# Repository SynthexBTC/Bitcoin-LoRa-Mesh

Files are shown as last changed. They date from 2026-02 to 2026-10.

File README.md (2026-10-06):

# Bitcoin-LoRa-Mesh
A decentralized Bitcoin Mesh network that communicates over long-range LoRa radio, enabling off-grid transactions
<br>
Bitcoin Becomes Truly Uncensorable<br>
Broadcast Bitcoin transactions over LoRa mesh networks<br>
No Internet required at the sender's location<br>
<br>
## The nRF52840 E22P868M30S Solar LoRa Node
<br>

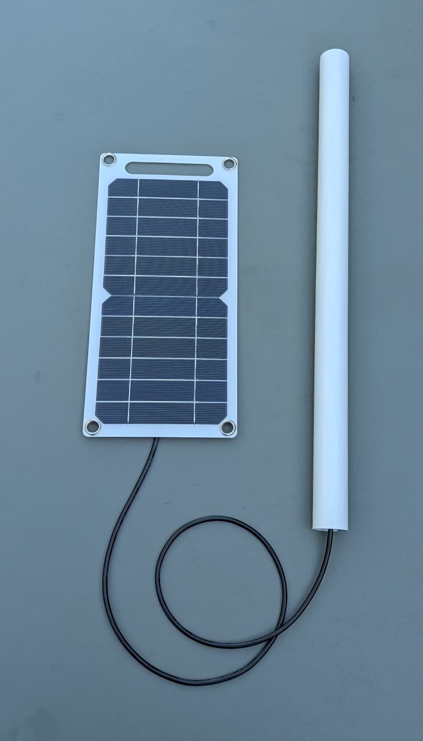
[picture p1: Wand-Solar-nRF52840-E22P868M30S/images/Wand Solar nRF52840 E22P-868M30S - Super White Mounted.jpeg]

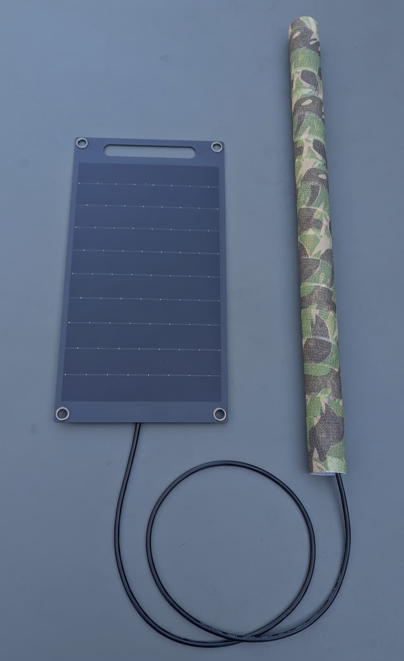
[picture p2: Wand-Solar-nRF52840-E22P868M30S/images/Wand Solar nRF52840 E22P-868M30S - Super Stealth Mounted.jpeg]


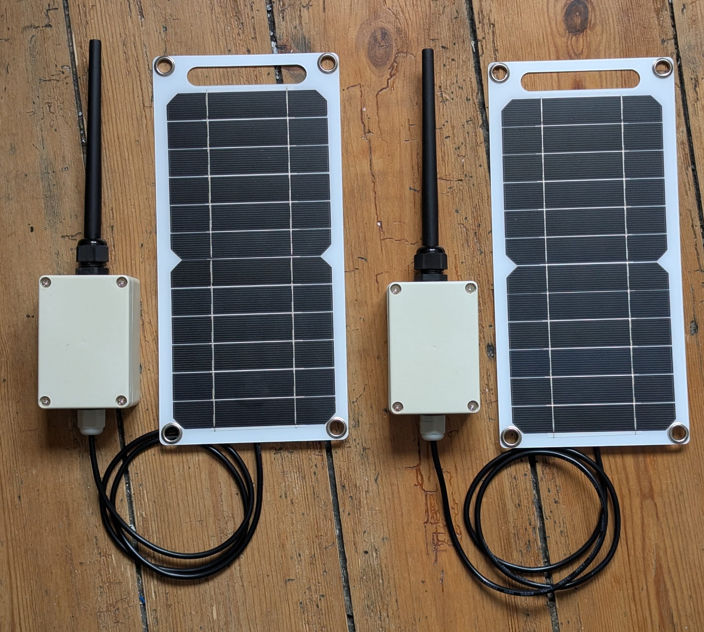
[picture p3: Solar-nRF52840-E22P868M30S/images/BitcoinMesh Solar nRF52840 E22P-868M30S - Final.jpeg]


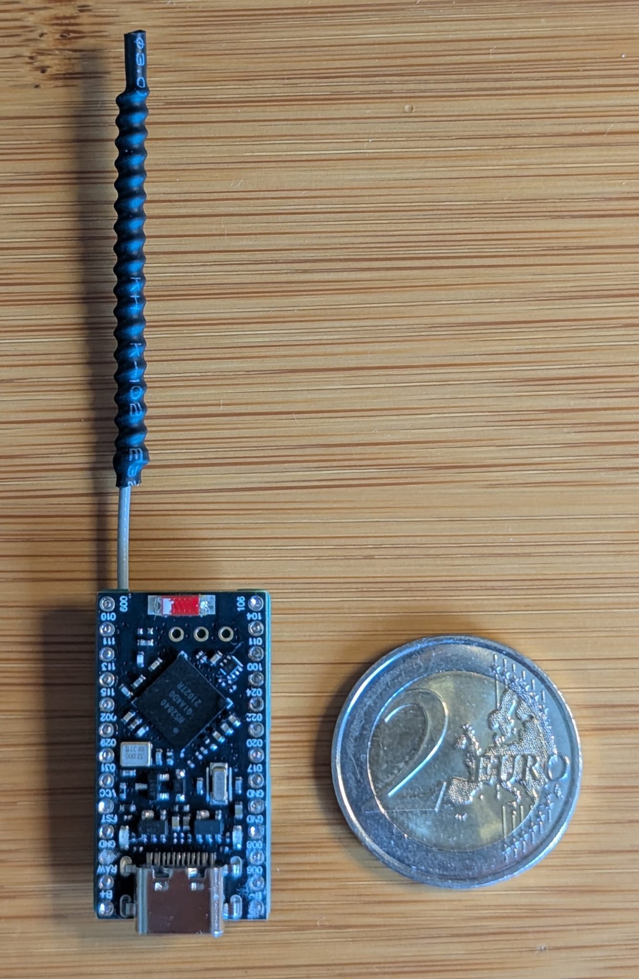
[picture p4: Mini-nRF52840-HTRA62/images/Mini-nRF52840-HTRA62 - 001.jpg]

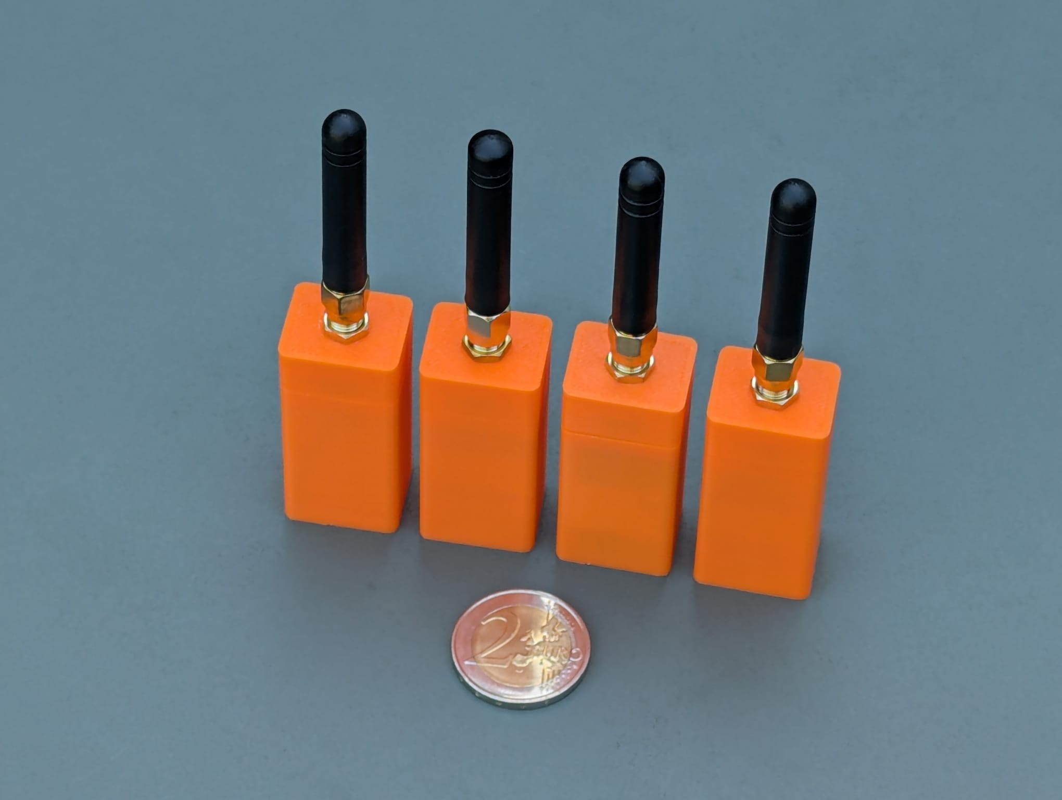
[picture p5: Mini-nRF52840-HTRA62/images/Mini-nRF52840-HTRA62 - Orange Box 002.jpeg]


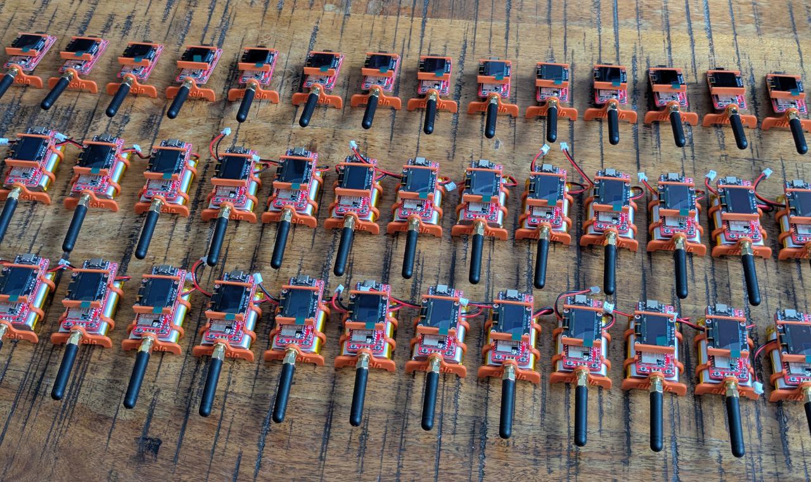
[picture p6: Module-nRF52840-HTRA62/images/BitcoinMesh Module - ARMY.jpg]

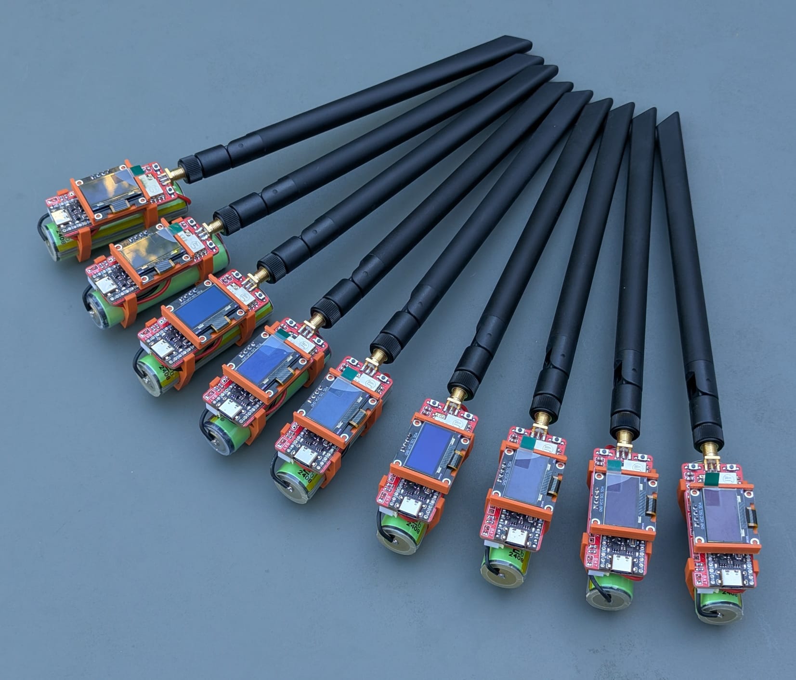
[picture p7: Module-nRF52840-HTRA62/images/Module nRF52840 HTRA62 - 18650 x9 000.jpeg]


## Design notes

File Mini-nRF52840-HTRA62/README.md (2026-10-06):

# Mini nRF52840 SX1262 LoRa Node


  
Ultra Mini and Ultra Low Power LoRa Node  
Only 33mm x 18mm x 8mm !

The total power consumption is 6mA when receiving and about 100mA when transmitting.   
which for Meshcore in "Moderate Repeater" is an average current of **7mA** !
  
Tiny but with Big capabilities :  
- Ultra Low Power nRF52840 SoC
- Bluetooth 5 & Zigbee
- HTRA62 LoRa module with 22dBm power
- TP4054 Li-ion charger for mini solar panel
- Battery voltage monitoring

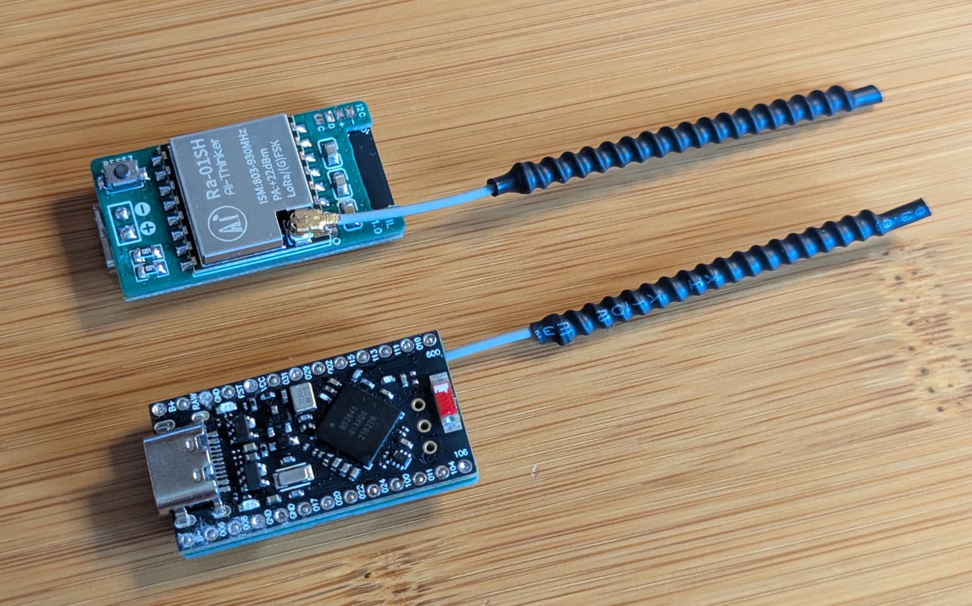
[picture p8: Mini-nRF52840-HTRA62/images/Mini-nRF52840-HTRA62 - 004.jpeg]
  
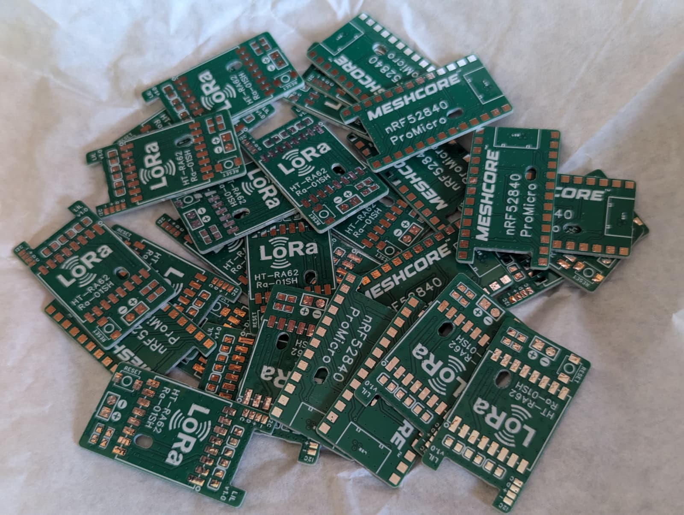
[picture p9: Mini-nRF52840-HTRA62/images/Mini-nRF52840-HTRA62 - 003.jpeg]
  
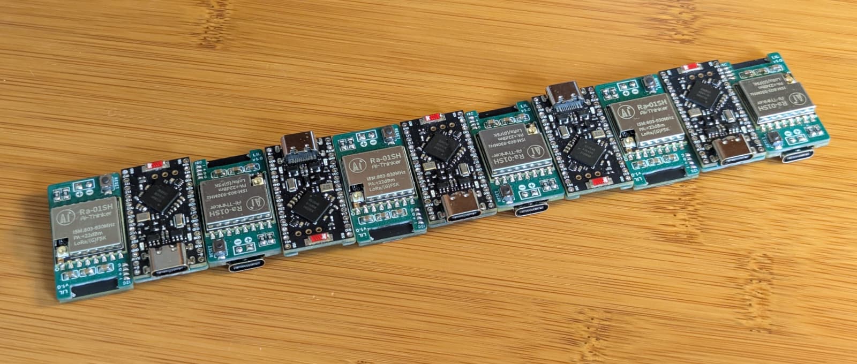
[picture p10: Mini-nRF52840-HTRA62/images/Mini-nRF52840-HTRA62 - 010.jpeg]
  
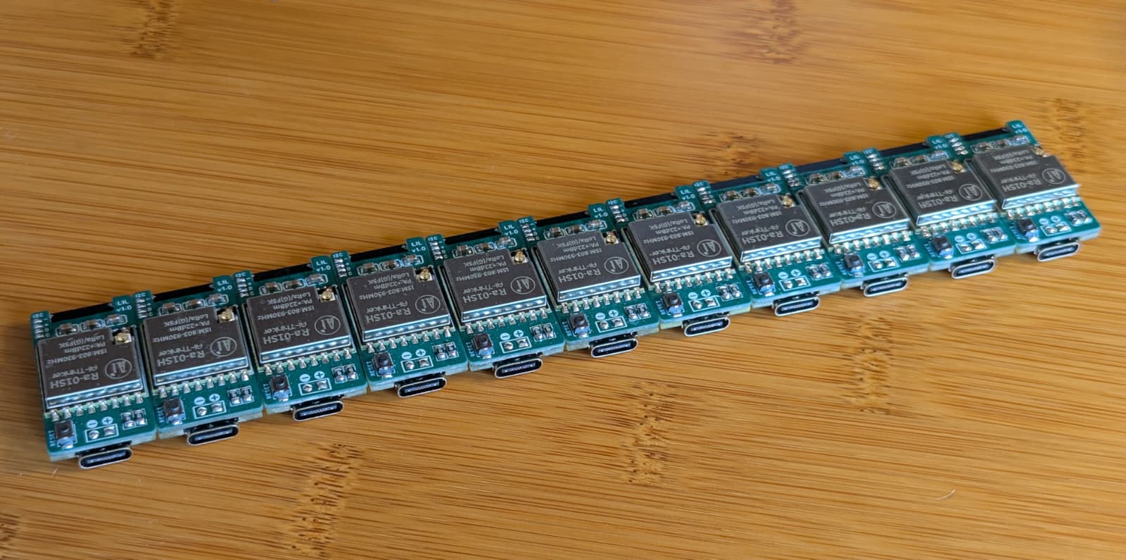
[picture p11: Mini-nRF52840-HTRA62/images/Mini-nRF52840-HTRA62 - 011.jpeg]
  
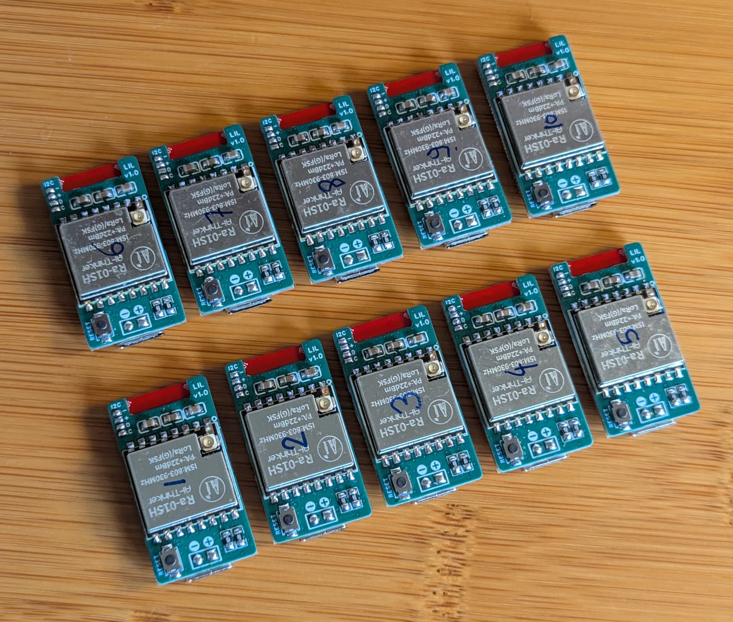
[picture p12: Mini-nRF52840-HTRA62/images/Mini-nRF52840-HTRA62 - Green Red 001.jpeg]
  
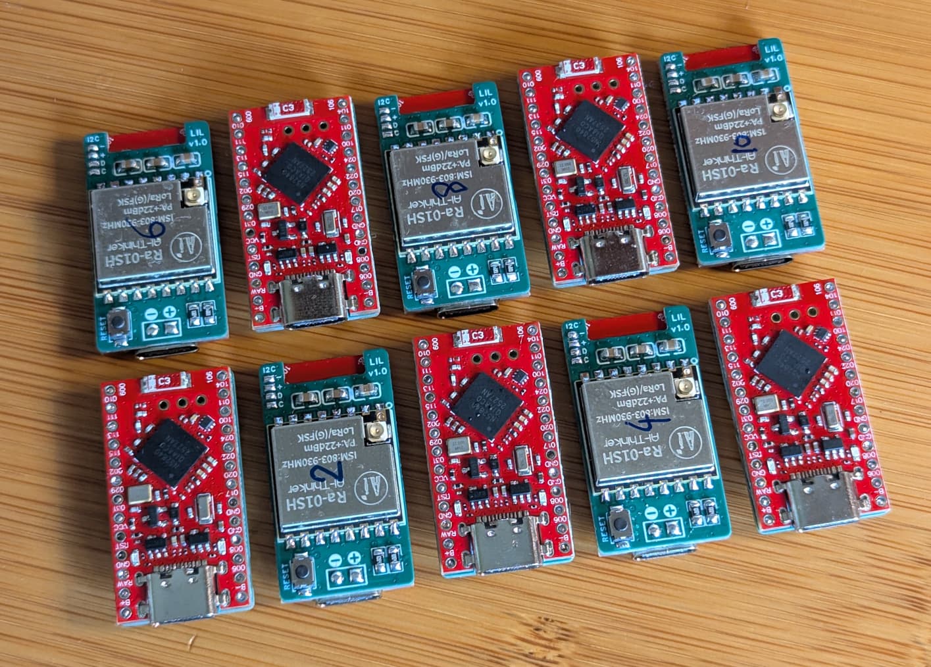
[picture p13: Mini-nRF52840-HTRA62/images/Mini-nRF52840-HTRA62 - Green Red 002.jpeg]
  

### With case and 500mAh 902030 li-Po battery
  
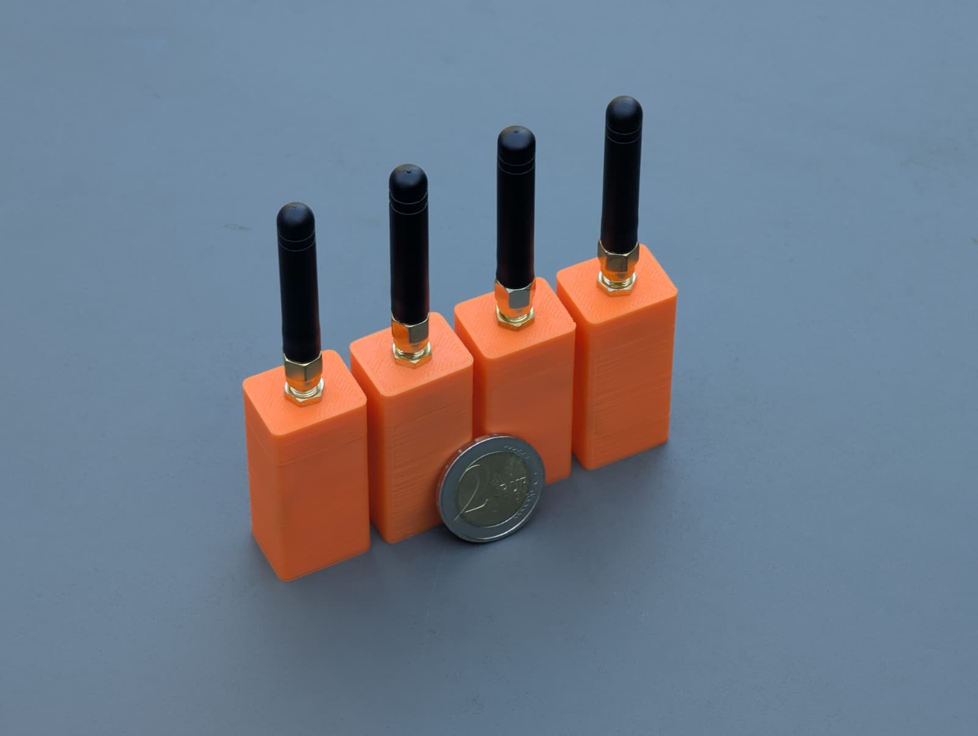
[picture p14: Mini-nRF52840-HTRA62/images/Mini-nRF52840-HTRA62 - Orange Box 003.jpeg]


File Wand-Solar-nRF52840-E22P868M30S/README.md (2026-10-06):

# nRF52840 E22P868M30S Solar Wand LoRa Node

### Super White Wand
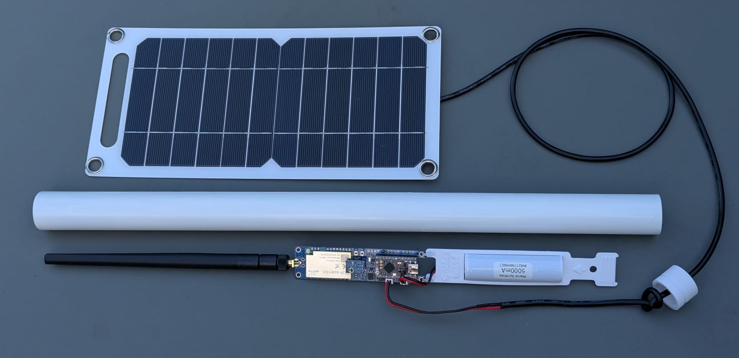
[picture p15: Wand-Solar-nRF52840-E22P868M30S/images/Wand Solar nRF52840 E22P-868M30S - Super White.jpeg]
<p>&nbsp;&nbsp;&nbsp;&nbsp;</p>

### Super Stealth Wand
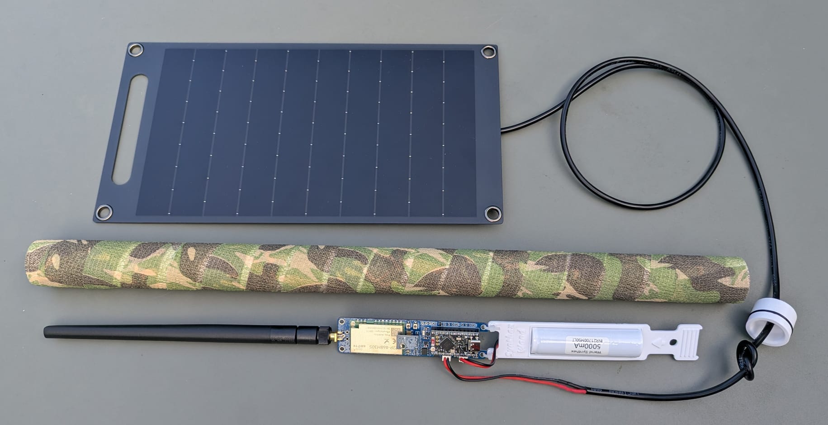
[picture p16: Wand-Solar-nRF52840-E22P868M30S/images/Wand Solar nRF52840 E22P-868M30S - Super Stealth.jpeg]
<p>&nbsp;&nbsp;&nbsp;&nbsp;</p>

<br>
Ultra Low Power Solar LoRa Node (on average 19mA)<br>
Can operate for weeks during the dark days of winter<br>
Compatible with Meshcore, Meshtastic, ...<br>
<br>
•	LoRa module <b>E22P-868M30S</b> (<b>1 Watt</b>, PA up to 32dBm, Ultra LNA, SAW filters, …)<br>
•	<b>nRF52840</b> SoC UltraLow Power<br>
•	Telemetry : Batteries Voltage, Temperature and Humidity (<b>AHT10</b>)<br>
•	<b>Ultra Smart BMS watchdog for the battery via PIC16F13114 : Battery management module that monitors voltage and temperature to automatically protect/cut off/re-enable the battery and charging, 
reset nRF, configurable via USB Serial link : <a href="https://github.com/SynthexBTC/Bitcoin-LoRa-Mesh/tree/main/Wand-Solar-nRF52840-E22P868M30S/watchdog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">INFOS</a><br>
•	18650 or 21700 Li-ion Branded battery with a minimum capacity of 5000 mAh<br>
•	IPX6 resistant enclosure in a <b>32mm diameter</b>, 50cm high rod, containing the antenna, module and batteries<br>
•	<b>Solar Panel</b> waterproof and unbreakable <b>6 Watts Actual</b> (325 cm² = <b>50 square inches</b>)<br>
•	<b>3 dBi antenna</b> (TX868-JKD-20) Tuned with enclosure : SWR≈1 @869,5MHz (with NanoVNA) <br>
<br>
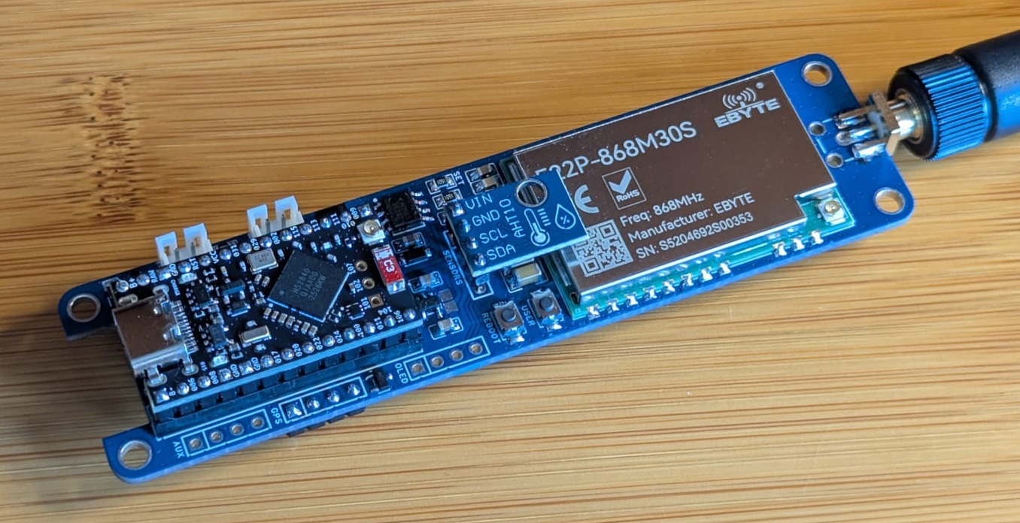
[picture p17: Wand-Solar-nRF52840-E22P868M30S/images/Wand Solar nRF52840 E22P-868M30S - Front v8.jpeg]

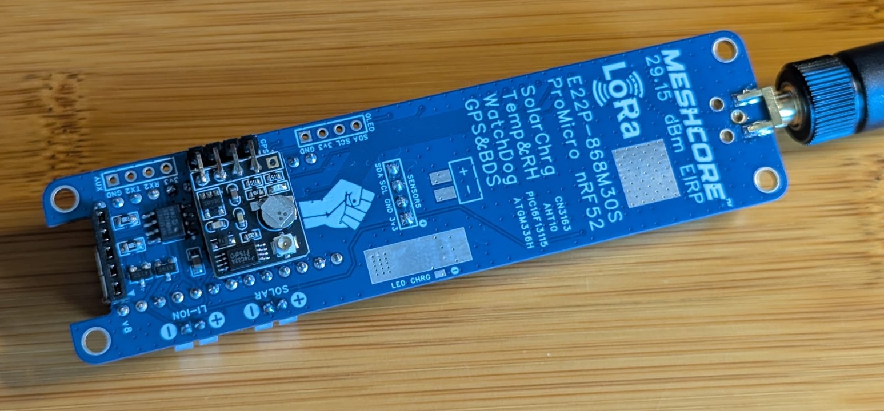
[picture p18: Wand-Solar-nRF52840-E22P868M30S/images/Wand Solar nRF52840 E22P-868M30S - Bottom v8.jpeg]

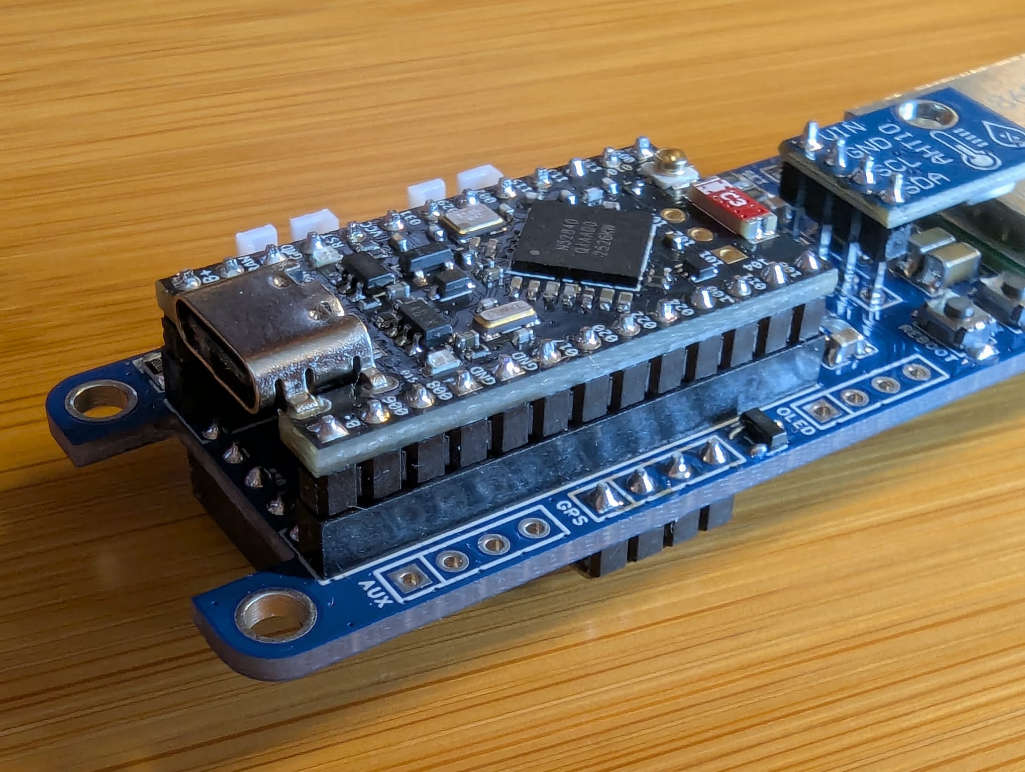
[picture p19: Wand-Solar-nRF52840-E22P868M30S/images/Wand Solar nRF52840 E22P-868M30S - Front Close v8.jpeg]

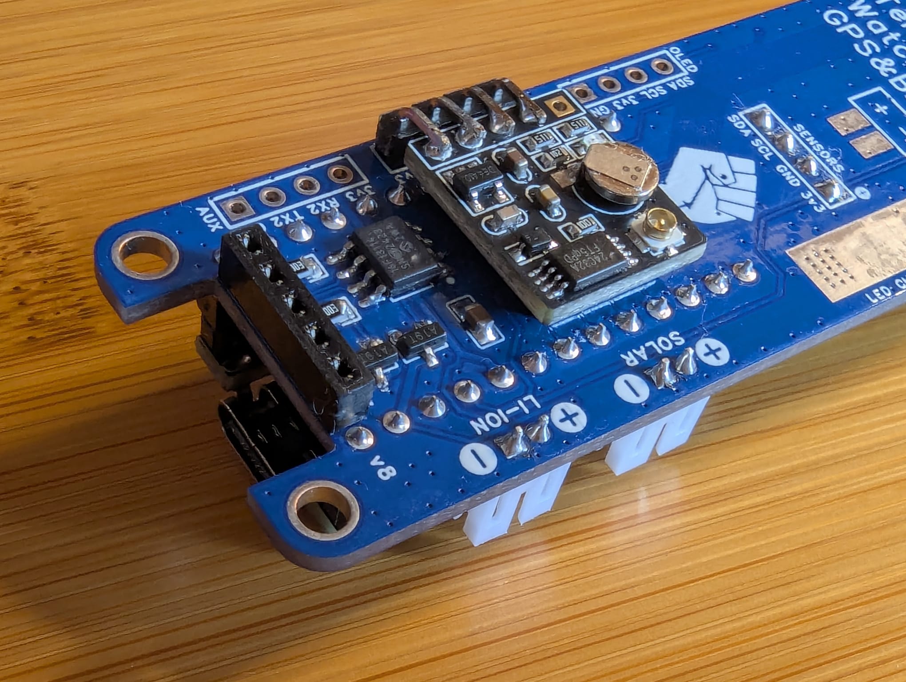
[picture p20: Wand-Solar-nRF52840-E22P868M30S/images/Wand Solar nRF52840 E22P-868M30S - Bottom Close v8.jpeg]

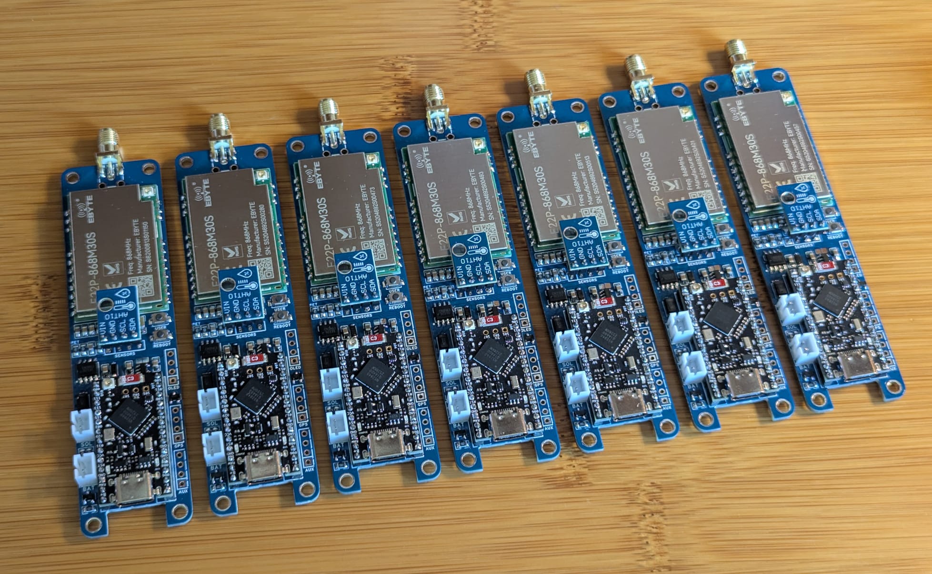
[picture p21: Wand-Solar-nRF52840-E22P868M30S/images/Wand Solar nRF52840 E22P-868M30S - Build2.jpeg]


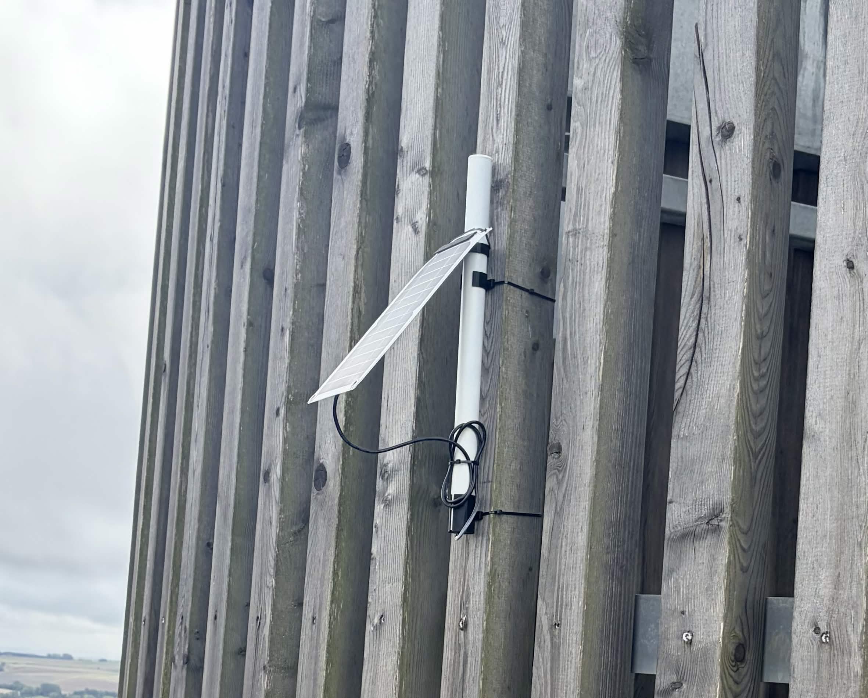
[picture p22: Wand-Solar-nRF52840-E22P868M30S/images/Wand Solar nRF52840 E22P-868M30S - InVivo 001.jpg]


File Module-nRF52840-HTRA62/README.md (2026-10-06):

# BitcoinMesh LoRa Module

BitcoinMesh LoRa Module with UltraLow-Power nRF52840 SoC and 2000mAh LiPo Battery

- Connection via USB or Bluetooth
- OLED Screen
- UltraLow-Power nRF52840 SoC
- HT-RA62 (SX1262) 22dBm LoRa Wireless Module
- On Board LiPo Battery management
- Ready for MESHTASTIC and MESHCORE firmwares

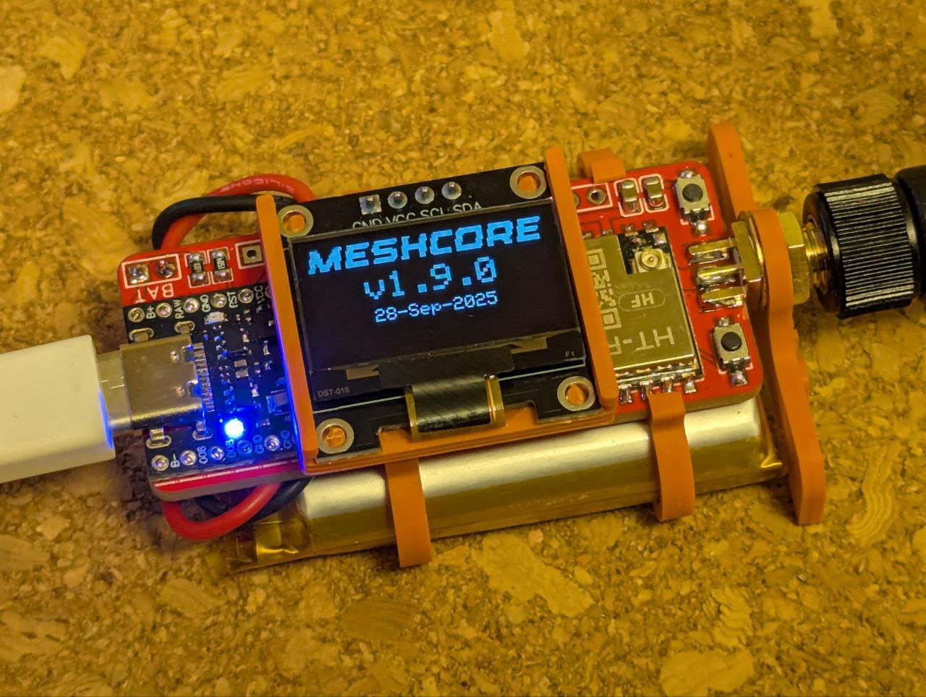
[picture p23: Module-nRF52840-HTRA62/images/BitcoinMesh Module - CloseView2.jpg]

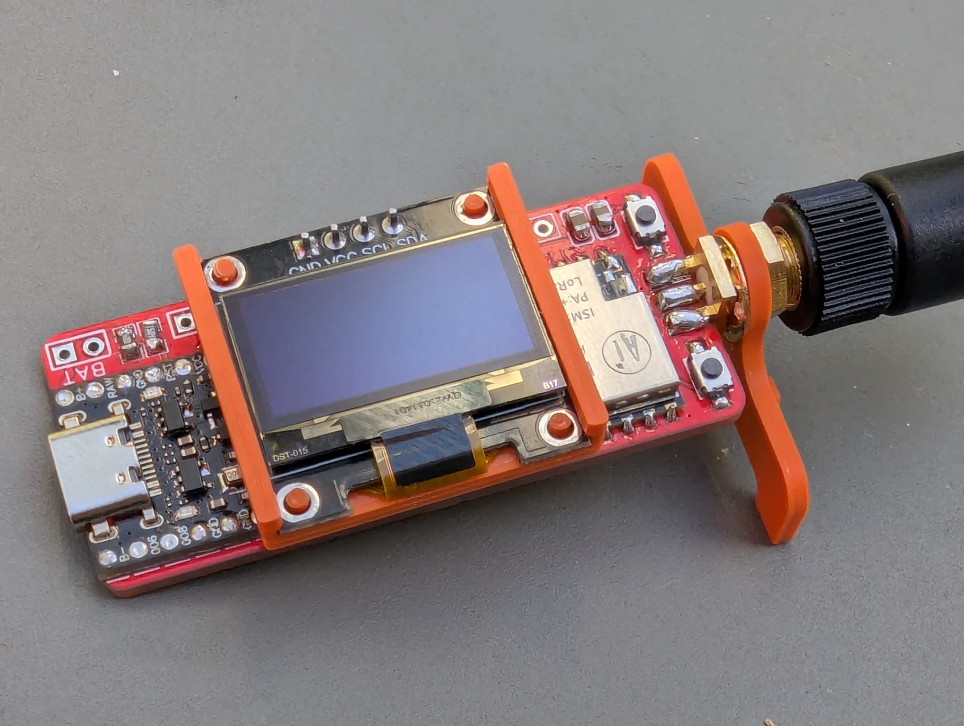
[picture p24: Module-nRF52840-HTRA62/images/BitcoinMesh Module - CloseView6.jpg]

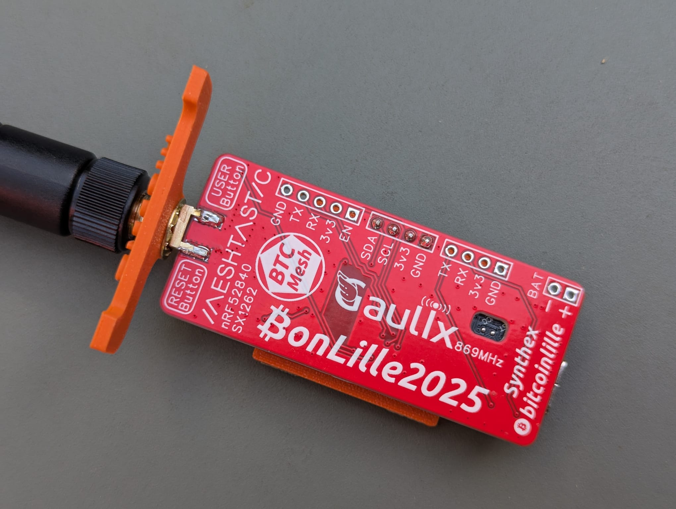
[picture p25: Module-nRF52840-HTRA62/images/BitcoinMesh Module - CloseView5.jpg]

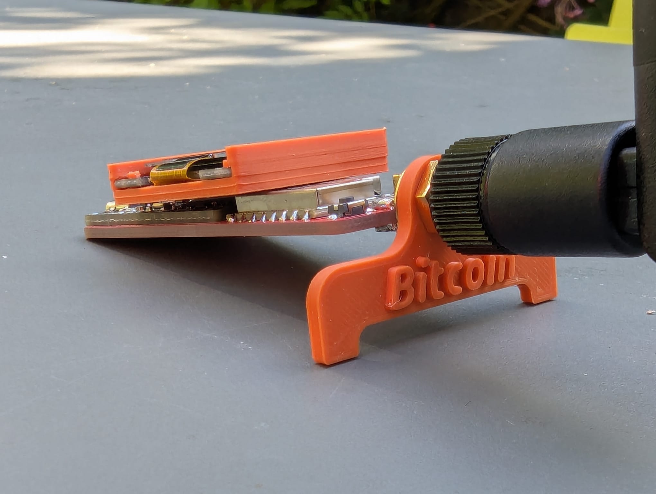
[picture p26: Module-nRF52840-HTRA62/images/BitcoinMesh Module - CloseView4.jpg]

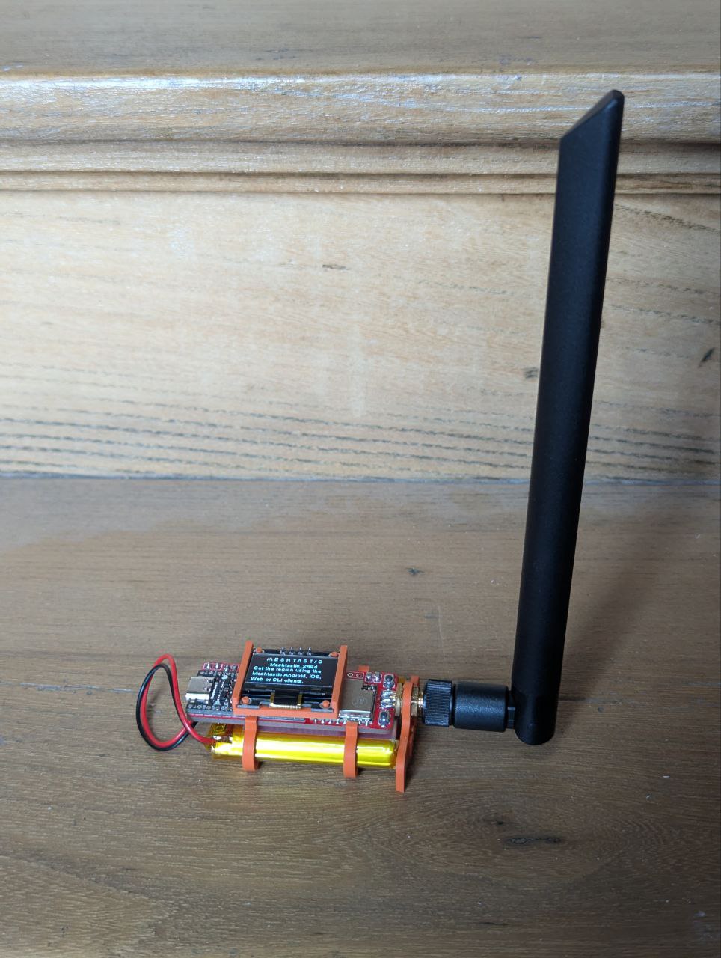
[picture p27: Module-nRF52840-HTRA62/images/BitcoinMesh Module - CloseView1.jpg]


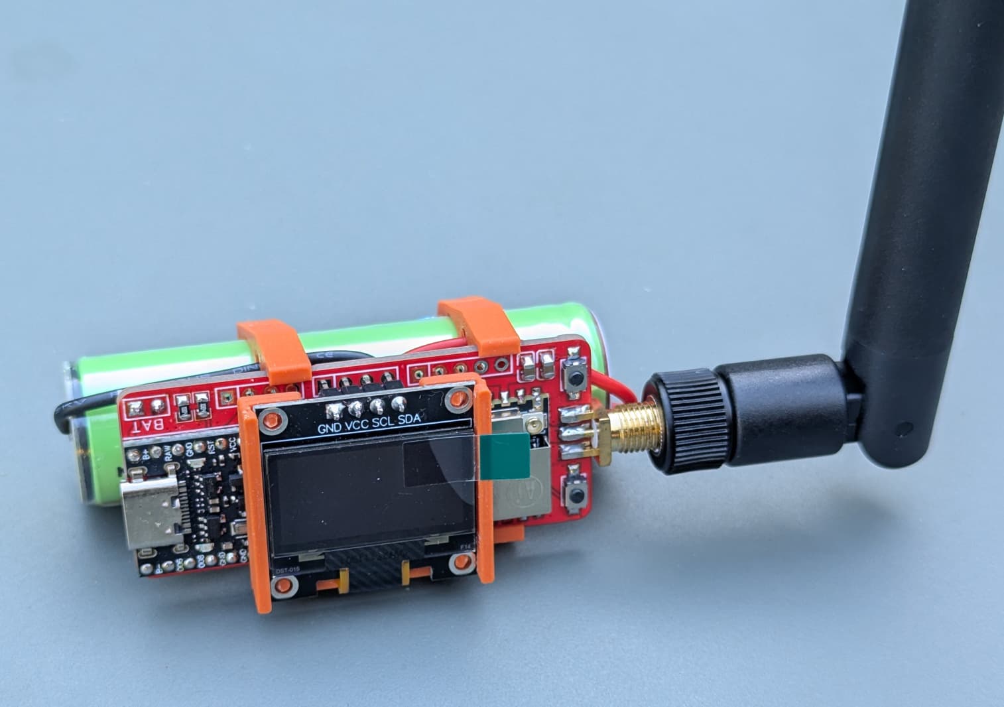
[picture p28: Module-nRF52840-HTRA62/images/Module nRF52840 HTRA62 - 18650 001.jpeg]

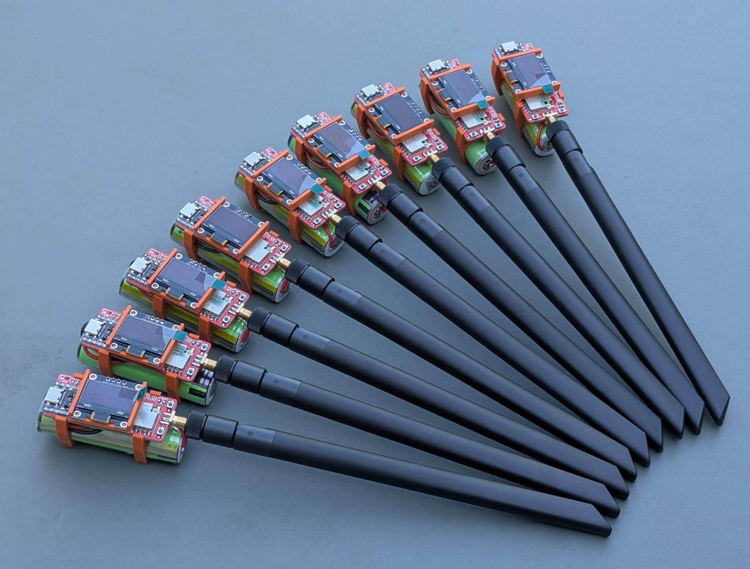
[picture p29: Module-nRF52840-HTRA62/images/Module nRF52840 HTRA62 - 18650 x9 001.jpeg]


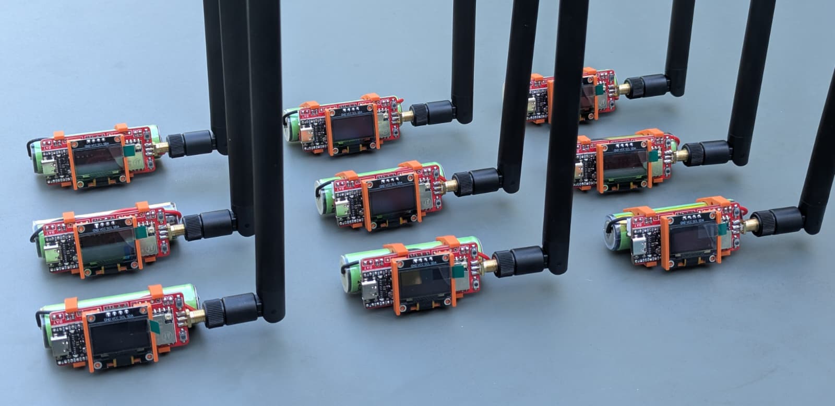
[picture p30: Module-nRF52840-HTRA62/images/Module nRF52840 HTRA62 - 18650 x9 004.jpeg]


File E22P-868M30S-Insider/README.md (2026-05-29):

# Why use E22P-868M30S

A completely new generation, coming out at the end of 2025 !<br>

This module adds a true RF front end module (RF FEM) comprising :
- A power amplifier (PA) up to 32 dBm at 868 MHz (see datasheet)
- A low-noise amplifier (LNA)
- Several surface acoustic wave (SAW) filters
- RF Ceramic Chips
- A high-precision active temperature compensated crystal oscillator

Compared to the previous old generation E22-900M30S,<br>
these modules significantly improve out-of-band spurious signal suppression capabilities,<br>
and offer enhanced anti-interference capabilities as well as increased receive sensitivity.<br>

<br>

Change of pin name from E22-900M30S to E22P-868M30S :
- RXEN pin is now EN pin
- TXEN pin is now T/R CTRL pin

The EN pin must now always be set to ON.<br>
However, to ensure good confuguration, full power and reduced floor noise,<br><b>it must be grounded for 3 seconds during startup !</b><br>
<br>

## Power Output @868MHz (dBm) - SX1262 Power Setting (dBm) - Power Supply (V) 
<table>
  <thead>
    <tr>
      <th>Pset</th>
      <th>5.0 V</th>
      <th>4.2 V</th>
      <th>3.7 V</th>
      <th>3.3 V</th>
    </tr>
  </thead>
  <tbody>
    <tr><th>-9</th><td>11.7</td><td>11.2</td><td>10.9</td><td>10.7</td></tr>
    <tr><th>-8</th><td>12.7</td><td>12.2</td><td>11.9</td><td>11.7</td></tr>
    <tr><th>-7</th><td>13.7</td><td>13.2</td><td>12.9</td><td>12.7</td></tr>
    <tr><th>-6</th><td>14.7</td><td>14.2</td><td>13.9</td><td>13.7</td></tr>
    <tr><th>-5</th><td>15.7</td><td>15.2</td><td>14.9</td><td>14.7</td></tr>
    <tr><th>-4</th><td>16.7</td><td>16.2</td><td>15.9</td><td>15.7</td></tr>
    <tr><th>-3</th><td>17.7</td><td>17.2</td><td>16.9</td><td>16.7</td></tr>
    <tr><th>-2</th><td>18.7</td><td>18.2</td><td>17.9</td><td>17.7</td></tr>
    <tr><th>-1</th><td>19.7</td><td>19.2</td><td>18.9</td><td>18.7</td></tr>
    <tr><th>0</th><td>20.7</td><td>20.2</td><td>19.9</td><td>19.7</td></tr>
    <tr><th>1</th><td>21.7</td><td>21.2</td><td>20.9</td><td>20.7</td></tr>
    <tr><th>2</th><td>22.7</td><td>22.2</td><td>21.9</td><td>21.7</td></tr>
    <tr><th>3</th><td>23.7</td><td>23.2</td><td>22.9</td><td>22.7</td></tr>
    <tr><th>4</th><td>24.7</td><td>24.2</td><td>23.9</td><td>23.7</td></tr>
    <tr><th>5</th><td>25.7</td><td>25.2</td><td>24.9</td><td>24.7</td></tr>
    <tr><th>6</th><td>26.6</td><td>26.1</td><td>25.8</td><td>25.6</td></tr>
    <tr><th>7</th><td>27.6</td><td>27.1</td><td>26.8</td><td>26.6</td></tr>
    <tr><th>8</th><td>28.5</td><td>27.9</td><td>27.6</td><td>27.4</td></tr>
    <tr><th>9</th><td>29.4</td><td>28.6</td><td>28.3</td><td>28.0</td></tr>
    <tr><th>10</th><td>30.3</td><td>29.3</td><td>28.8</td><td>28.4</td></tr>
    <tr><th>11</th><td>30.7</td><td>29.6</td><td>29.1</td><td>28.6</td></tr>
    <tr><th>12</th><td>31.1</td><td>29.9</td><td>29.4</td><td>28.8</td></tr>
    <tr><th>13</th><td>31.4</td><td>30.2</td><td>29.6</td><td>28.9</td></tr>
    <tr><th>14</th><td>31.6</td><td>30.4</td><td>29.8</td><td>29.0</td></tr>
    <tr><th>15</th><td>31.8</td><td>30.6</td><td>29.9</td><td>29.0</td></tr>
    <tr><th>16</th><td>31.9</td><td>30.7</td><td>29.9</td><td>29.0</td></tr>
    <tr><th>17</th><td>32.0</td><td>30.8</td><td>30.0</td><td>29.0</td></tr>
    <tr><th>18</th><td>32.0</td><td>30.9</td><td>30.0</td><td>29.0</td></tr>
    <tr><th>19</th><td>32.1</td><td>30.9</td><td>30.0</td><td>29.0</td></tr>
    <tr><th>20</th><td>32.1</td><td>31.0</td><td>30.0</td><td>29.0</td></tr>
    <tr><th>21</th><td>32.1</td><td>31.0</td><td>30.0</td><td>29.0</td></tr>
    <tr><th>22</th><td>32.0</td><td>31.0</td><td>30.0</td><td>29.0</td></tr>
  </tbody>
</table>

<br>

## SF8301

The SF8301 is a Surface Acoustic Wave (SAW) filter, commonly used for high-frequency signal conditioning :
- Center Frequency: 868 MHz
- Bandwidth: 10 MHz

SAW Filters provide high-performance frequency selection, effectively separating and filtering signals from different frequency bands.<br>
This ensures smooth communication between communication devices while suppressing interference.<br>
This is essential for use in urban areas with Cellular mobile networks.<br>
<br>
Several surface acoustic wave (SAW) filters in E22P-868M30S is a game changer !

<br>

## KCT8102L

KCT8102L is a highly-integrated, RF Front-End Integrated Circuit which incorporates key RF functionality needed for a TDD-mode operating in the 860M to 930MHz ISM frequency bands. <br>
KCT8102L is integrated with a power amplifier (PA), a low noise amplifier (LNA) with bypass, and a single-pole, double-throw (SPDT) switch all in one device. <br>
KCT8102L is designed for ease of use and maximum flexibility, with different matching circuits, KCT8102L could achieve high power and high efficiency two operation status.<br>
KCT8102L has simple and low-voltage 1.6 to 3.6V control logic, and wide supply voltage range from 3.0 to 5.25V allowing the KCT8102L to be used in battery powered applications.<br>
KCT8102L is assembled in a compact, low-profile 3x3x0.77mm 16-lead LGA package. KCT8102L is the ideal RF front-end solution for implementing sub-GHz from 860M to 930MHz supporting multiple standards including LP-WAN (LoRa, Sigfox, etc.), Wi-SUN, and other loT applications.<br>
<br>
Integrated high-performance 860 to 930MHz Front-End Module<br>
Nominated voltage at 3.3V & 4.2V & 5V<br>
<br>
<b>+32.5dBm saturated output power at 5.0V High Power Matching</b><br>
+31.0dBm saturated output power at 5.0V High Efficiency Matching<br>
+31.0dBm saturated output power at 4.2V High Power Matching<br>
+29.5dBm saturated output power at 4.2V High Efficiency Matching<br>
+29.0dBm saturated output power at 3.3V High Power Matching<br>
+27.5dBm saturated output power at 3.3V High Efficiency Matching<br>
<br>
Integrated LNA with noise figure of 1.7dB at 5V & 4.2V & 3.3V<br>
Receive bypass path with low loss: 2.0dB at 5V & 4.2V & 3.3V<br>
Support external Receive filter<br>
ESD Protection Circuitry on All Ports<br>
Small package: LGA-16L, 3×3×0.77mm (MSL3, 260°C per JEDEC J-STD-020)<br>
RoHS and REACH Compliant<br>

<br>
<br>

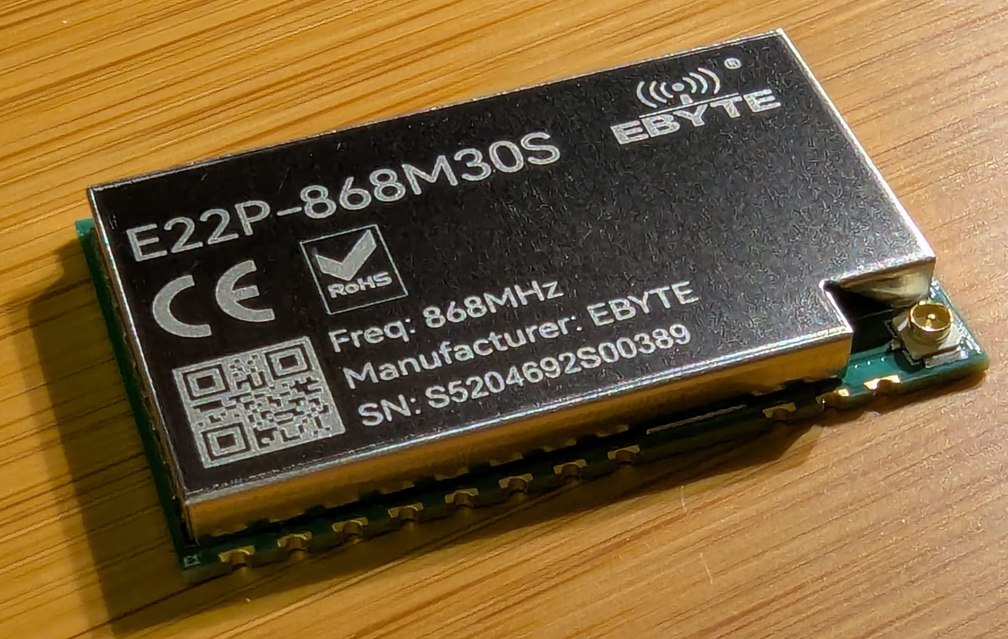
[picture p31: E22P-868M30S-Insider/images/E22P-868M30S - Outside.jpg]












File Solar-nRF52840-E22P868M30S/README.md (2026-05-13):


<br>

<br>

# nRF52840 E22P868M30S Solar LoRa Node
<br>
Ultra Low Power Solar LoRa Node (about 25mA)<br>
Can operate for weeks during the dark days of winter<br>
Compatible with Reticulum, Meshcore, Meshtastic, ...<br>
<br>
•	LoRa module <b>E22P-868M30S</b> (<b>1 Watt</b>, PA up to 32dBm, Ultra LNA, SAW filters, …)<br>
•	<b>nRF52840</b> SoC UltraLow Power<br>
•	Configuration OLED Screen<br>
•	Telemetry : Temperature and Humidity (<b>AHT20</b>)<br>
•	Telemetry : Batteries Voltage and Current (<b>INA219</b>)<br>
•	Watchdog and Scheduled <b>Automatic Reboot ever 1, 7 or 30 days</b> (PIC <b>16F13124</b>)<br>
•	RGB LED : Displays battery charging and Watchdog status<br>
•	Battery charging protection <b>NTC sensor</b>, temperature range from -2°C to 55°C<br>
•	<b>Dual-independent</b> battery protection. If one fails, the other works (2* DW07D)<br>
•	2* 18650 Li-ion batteries (<b>Lii-King4000</b>) for a total actual capacity of 7000mAh<br>
•	IP68 waterproof enclosure + double cable glands<br>
•	<b>Solar Panel</b> waterproof and unbreakable <b>6 Watts Actual</b> (325 cm² = <b>50 square inches</b>)<br>
•	<b>3 dBi antenna</b> (TX868-JKD-20) Tuned with enclosure : SWR≈1 @869,5MHz (with NanoVNA) <br>
•	Dedicated 64Mb Flash memory (W25Q64JV) to <b>Reticulum Transport Node</b> (Path table) <br>
<br>
To be at the maximum permitted power in Europe : <b>29,15 dBm EIRP</b>, <br>
The LoRa output power (sx1262) must be set to <b>8 dBm</b> in Meshtatic, Meshcore, RTNode, …<br>
<br>

<br>

<br>

<br>


<br>

<br>

<br>

<br>

<br>

<br>

<br>

<br>


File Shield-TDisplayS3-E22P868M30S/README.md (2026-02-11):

# T-Display-S3

T-Display-S3 is a board whose main control chip is ESP32-S3 N16R8.<br>
It is equipped with a 1.9-inch LCD color screen and two programmable buttons.

It is very well known in the Bitcoin world, as it is widely used by NerdMiners !

Adding an E22P-868M30S LoRa module makes it look like the Heltec Vision Master T190 (HT-VMT190), but much better !
- Better LoRa module (much, much more power and sensitivity)
- Better LCD quality (The screen bus is 8 bits wide, which allows for greater fluidity)



# T-Display-S3 - E22P-868M30S add-on board with IPX connector





# T-Display-S3 - E22P-868M30S add-on board with SMA connector






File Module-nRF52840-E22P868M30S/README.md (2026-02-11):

# BitcoinMesh LoRa HighPower Module

BitcoinMesh LoRa Module with E22P-868M30S 1Watt power output !

- Connection via Bluetooth
- OLED Screen
- UltraLow-Power nRF52840 SoC
- E22P-868M30S (SX1262) HighPower 1W+ LoRa Wireless Module
- On Board DC-DC regulator
- Ready for MESHTASTIC and MESHCORE firmwares
- Automatic humidity and temperature telemetry
- Can be mounted in a PVC pipe directly on the roof with the antenna

<p align="left">


</p>
<p align="left">

</p>





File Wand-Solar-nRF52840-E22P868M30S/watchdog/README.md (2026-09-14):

# Wand Smart Battery Management System

Battery **voltage** and **temperature** watchdog based on a PIC16F13114 microcontroller.



## What it does

This little module keeps an eye on your power and temperature, and takes care of your battery automatically.  

Every 16 seconds, it wakes up, takes a quick look at the power level and the temperature, then goes back to sleep.

## Operating Logic

- **At startup**: `BAT_EN` is set to the "battery disabled" state, a pulse is sent on `RESET_CPU`, then the module goes into permanent sleep (WDT wake-up every 16 s).
- **On each wake-up**, the module measures VDD and temperature, then applies the following rules:
  - If VDD stays **below the low threshold** `BAT_LOW_MV` for the confirmation duration `BAT_LOW_S` (10 min by default) → the battery is **disabled** (`BAT_EN` cut off).
  - If VDD exceeds the **re-enable threshold** `BAT_OK_MV` (after confirmation `BAT_OK_S`) → the battery is **re-enabled** (`BAT_EN`), followed by a pulse on `RESET_CPU`.
  - If VDD exceeds the **overvoltage threshold** `BAT_HIGH_MV` for the confirmation duration `BAT_HIGH_S` → **charging is disabled** (`CHRG_EN`), independently of the temperature-based charging window below. It is **re-enabled** only once VDD has been back at or below `BAT_HIGH_MV` for `BAT_HIGH_S` as well (symmetric confirmation on both edges of this threshold, no instant hysteresis).
  - If temperature goes outside the range `[TEMP_LOW_C ; TEMP_HIGH_C]` (0 °C to 47 °C by default) → **charging is disabled** (`CHRG_EN`); within the normal range, charging is allowed **unless** the overvoltage cutoff above is also active (`CHRG_EN` follows the logical AND of "temperature in range" and "no overvoltage cutoff").
  - If temperature exceeds `TEMP_DANGER_HIGH_C` (65 °C by default) or drops below `TEMP_DANGER_LOW_C` (-20 °C by default) → **total safety shutdown** (both battery and charging disabled), with absolute priority over any other logic.
  - When temperature returns to the normal range after a thermal emergency, the battery is **re-enabled immediately** (without waiting for the `BAT_OK_MV`/`BAT_OK_S` confirmation), provided VDD is not below the low threshold.

- **Periodic Reboot**, Automatic reboot period after `REBOOT_D` days. (battery cutoff/re-enable + nRF52840 reset pulse)

- **The key feature lies in the management of the reset (RESET_BTN) and, above all, the complete shutdown (BAT_EN) of the Meshcore board. This makes it possible to reboot even the most stubborn boards and fully discharge the capacitors to ensure a clean restart.**


  




⚠️ **Note on timing accuracy**: the module only wakes up every 16 seconds (no real-time clock). Confirmation durations (`BAT_LOW_S`, `BAT_OK_S`, `BAT_HIGH_S`) are therefore always **rounded up to the next multiple of 16 s**. For example, an entered value between 1 and 16 s results in an actual delay of 16 s, between 17 and 32 s an actual delay of 32 s, and so on. The value stored and read back via `GET` remains exactly the one entered; only the physically observed delay is quantized in 16 s steps (always rounded up, so never less protective than requested — at worst 15 s more).

## Power consumption

About half a microamp on average, low enough to run for years on a battery.

---

## Connecting for Configuration (Serial Link)

Configuration is done via the module's ICSP port, connected to a USB-to-serial adapter.

| ICSP Port | ↔ | USB-Serial Adapter |
|---|---|---|
| pin 1  | ↔ |  |
| pin 2  | ↔ |  |
| pin 3 = GND | ↔ | GND |
| pin 4 = ICSPDAT = **TX** | ↔ | **RX** |
| pin 5 = ICSPCLK = **RX** | ↔ | **TX** |

**Serial link parameters:**

- Speed: **1200 baud**
- Format: **8N1** (8 data bits, no parity, 1 stop bit)

**Please note : the Wand must be powered by its own battery to be configured.**





---

## Command Syntax

Two commands are available:

- `GET NAME` → response `NAME=value` or `ERR` (or, for `GET INFOS`, a multi-line response, see below)
- `SET NAME value` → response `OK` or `ERR`

**Important: a successful `SET` immediately saves all parameters to Flash memory** (no separate save command needed).

Commands and parameter names are case-insensitive.

---

## Read-Only Commands (Not Adjustable)

| Command | Description | Response |
|---|---|---|
| `GET TEMP` or `GET TEMPERATURE` | Current temperature | in °C |
| `GET VOLTAGE` or `GET MV` | Current VDD voltage | in mV (0 = measurement failure) |
| `GET VERSION` or `GET VER` | Firmware version | version string |
| `GET INFOS` | Summary of the main thresholds, grouped by topic | 4 lines — see format below |

### `GET INFOS` response format

One line per group, current values separated by ` ; `:

```
BAT_MV : BAT_LOW_MV ; BAT_OK_MV ; BAT_HIGH_MV
BAT_S : BAT_LOW_S ; BAT_OK_S ; BAT_HIGH_S
TEMP_C : TEMP_DANGER_LOW_C ; TEMP_LOW_C ; TEMP_HIGH_C ; TEMP_DANGER_HIGH_C
REBOOT_D : REBOOT_D
```

---

## Adjustable Parameters (GET/SET)

| Name | Meaning | Unit | Min | Max | Default |
|---|---|---|---|---|---|
| `BAT_LOW_MV` | VDD low threshold → disables `BAT_EN` (after confirmation `BAT_LOW_S`) | mV | 0 | 8191 | 3300 |
| `BAT_OK_MV` | VDD re-enable threshold → re-enables `BAT_EN` + `RESET_CPU` pulse (after confirmation `BAT_OK_S`) | mV | 0 | 8191 | 3800 |
| `BAT_LOW_S` | Confirmation duration before battery shutdown, 16 s resolution | s | 0 | 4080 | 600 |
| `BAT_OK_S` | Confirmation duration before re-enabling `BAT_EN`, 16 s resolution | s | 0 | 4080 | 0 |
| `BAT_HIGH_MV` | VDD overvoltage threshold → disables `CHRG_EN` (charging), independently of `TEMP_LOW_C`/`TEMP_HIGH_C` below (after confirmation `BAT_HIGH_S`) | mV | 0 | 8191 | 4280 |
| `BAT_HIGH_S` | Confirmation duration, applied both before disabling and before re-enabling `CHRG_EN` on the `BAT_HIGH_MV` threshold (symmetric), 16 s resolution | s | 0 | 4080 | 0 |
| `TEMP_LOW_C` | Below this threshold → `CHRG_EN` disabled | °C | -8192 | 8191 | 0 |
| `TEMP_HIGH_C` | Above this threshold → `CHRG_EN` disabled | °C | -8192 | 8191 | 47 |
| `TEMP_DANGER_HIGH_C` | Above this threshold → total shutdown (`BAT_EN` + `CHRG_EN`) | °C | -8192 | 8191 | 65 |
| `TEMP_DANGER_LOW_C` | Below this threshold → total shutdown (`BAT_EN` + `CHRG_EN`) | °C | -8192 | 8191 | -20 |
| `TEMP_OFFSET_C` | Additive offset applied to the temperature reading (measured_c + offset) | °C | -8192 | 8191 | -2 |
| `REBOOT_D` | Automatic reboot period (battery cut/re-enable + reset pulse); 0 = disabled | days | 0 | 8191 | 0 |
| `RESET_PULSE_MS` | Duration of the `RESET_CPU` pulse | ms | 0 | 8191 | 1000 |
| `BAT_CUT_PULSE_MS` | Duration of `BAT_EN` cutoff (at startup and before each periodic reboot) | ms | 0 | 8191 | 5000 |

---

## Example Session

```
> GET VERSION
VERSION=v8.2.6

> GET TEMP
TEMP=23

> GET VOLTAGE
VOLTAGE=3980

> SET BAT_LOW_MV 3200
OK

> GET BAT_LOW_MV
BAT_LOW_MV=3200

> SET BAT_LOW_MV 99999
ERR

> GET INFOS
BAT_MV : 3200 ; 3800 ; 4280
BAT_S : 600 ; 0 ; 0
TEMP_C : -20 ; 0 ; 47 ; 65
REBOOT_D : 0
```

(`ERR` is returned if the parameter name is unknown, if the value is not a valid integer, or if it is outside the Min/Max bounds listed above.)

---

## Points of Attention for the User

- A `VOLTAGE`/`MV` value of **0** indicates a **voltage measurement failure**, not an actual zero voltage (physically impossible during normal operation).
- The total safety shutdown (high or low thermal emergency) takes **absolute priority over all VDD/charging logic**: it applies even when voltage conditions would normally call for re-enabling the battery.
- `BAT_OK_MV`/`BAT_OK_S` control **re-enabling the battery** (`BAT_EN`); `BAT_HIGH_MV`/`BAT_HIGH_S` are a **separate, independent** overvoltage cutoff on **charging** (`CHRG_EN`) only, the two thresholds are not related and can be set independently.
- The `TEMP_OFFSET_C` offset defaults to **-2 °C** (drift compensation); any value read via `GET TEMP` already includes this offset.
- Any change made via `SET` is **saved immediately and automatically** to Flash memory, it is therefore retained after a power loss.

---

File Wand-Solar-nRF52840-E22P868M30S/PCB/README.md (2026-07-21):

&nbsp;&nbsp;&nbsp;&nbsp;&nbsp;&nbsp;

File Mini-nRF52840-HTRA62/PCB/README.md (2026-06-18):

&nbsp;&nbsp;&nbsp;&nbsp;&nbsp;&nbsp;

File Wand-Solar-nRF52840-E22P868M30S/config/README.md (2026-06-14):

# MeshCore Repeater Admin Configuration

## Initial Setup Commands

Run these commands via the CLI after flashing the firmware.

---

### Clock Synchronization
Sync the node clock from the connected GNSS module.
```
gps sync
```

---

### Power Management
Enable powersaving mode to reduce current consumption between LoRa events.
```
powersaving on
```

---

### Radio Configuration
Set frequency, bandwidth, spreading factor and coding rate.
```
set radio 869.618,62.5,8,8
```

| Parameter | Value | Description |
|---|---|---|
| Frequency | `869.618` MHz | EU868 band |
| Bandwidth | `62.5` kHz | |
| Spreading Factor | `8` | SF8 |
| Coding Rate | `8` | CR 4/8 |

---

### TX Power
Set transmit power in dBm.  
  
The power output must be set to 22 dBm.  
With the E22P-868M30S module powered by 3.3 volts, the output is approximately 28 dBm.  
The antenna gain is approximately 1.7 dBi and considering losses in connectors, we are therefore close to the legal limit of 29.15 dBm.  
```
set tx 22
```
> Maximum allowed value for the SX1262 in EU868: **22 dBm**.

---

### Duty Cycle
Set the airtime duty cycle limit.
```
set dutycycle 10
```
> 10% duty cycle — compliant with EU868 regulatory requirements.

---

## Full Setup Sequence

```
gps sync
set radio 869.618,62.5,8,8
set tx 22
set dutycycle 10
powersaving on
```

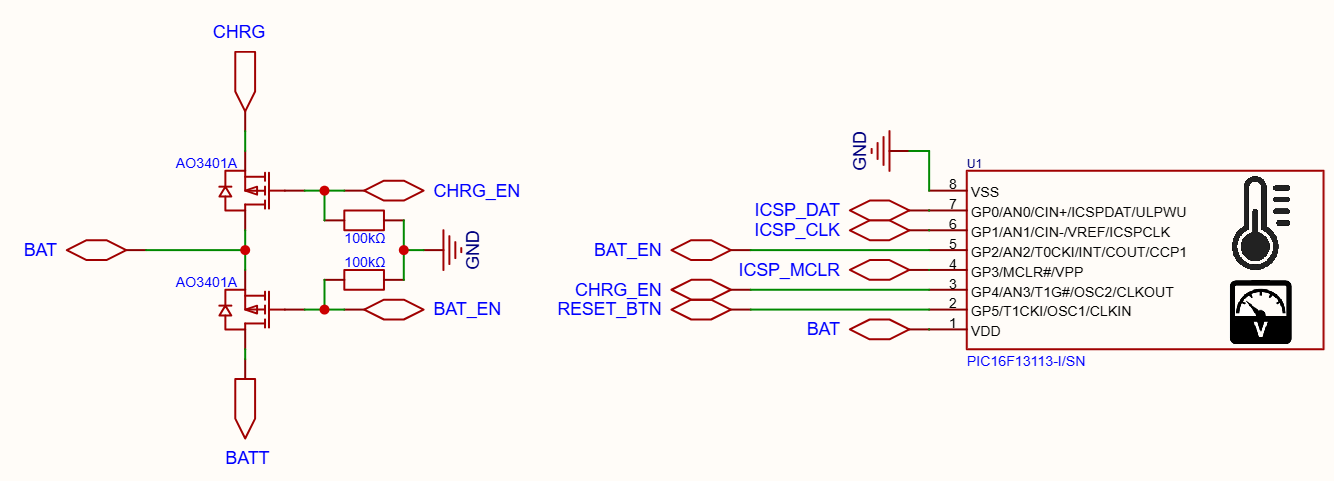
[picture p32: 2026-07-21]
Wand-Solar-nRF52840-E22P868M30S/images/Wand Solar nRF52840 E22P-868M30S - Schematics v8 WatchDog.png

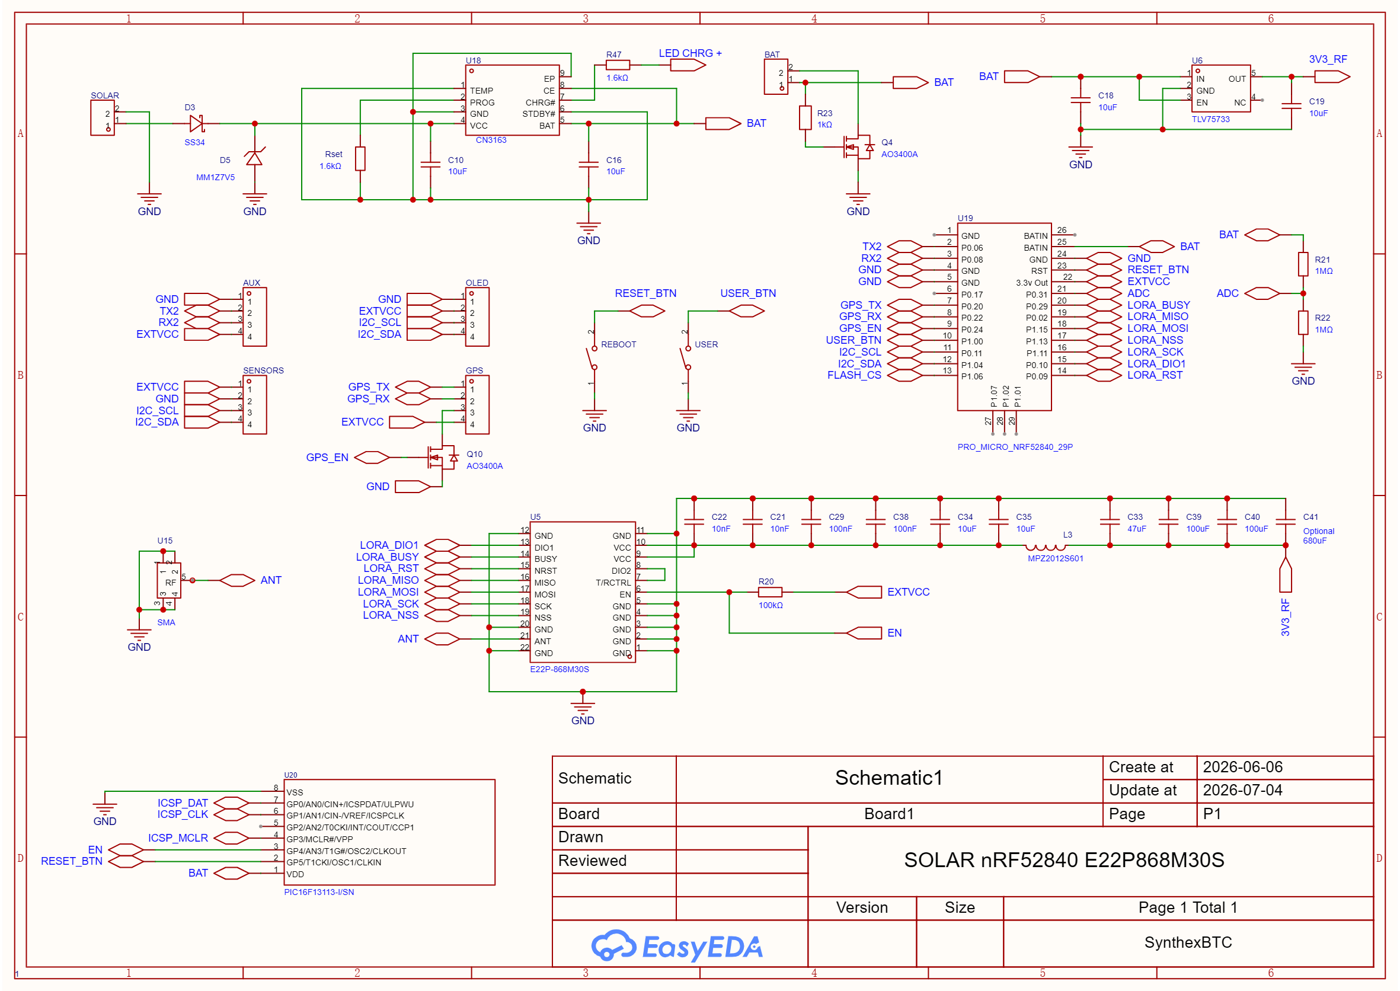
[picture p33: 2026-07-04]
Wand-Solar-nRF52840-E22P868M30S/images/Wand Solar nRF52840 E22P-868M30S - Schematics v6.png

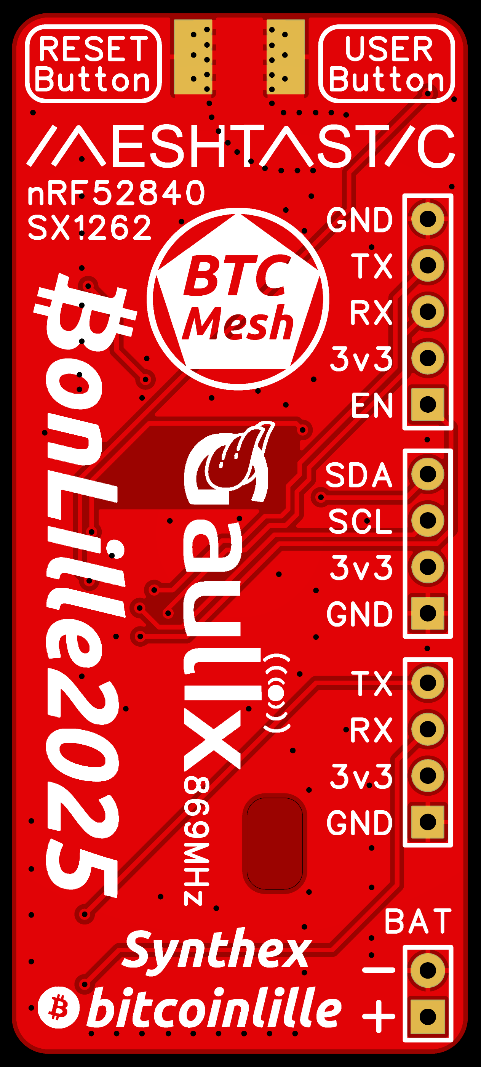
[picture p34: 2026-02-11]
Module-nRF52840-HTRA62/images/BitcoinMesh Module nRF52840 - PCB Bottom.png

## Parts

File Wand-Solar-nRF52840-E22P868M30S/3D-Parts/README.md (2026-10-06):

## 3D Parts

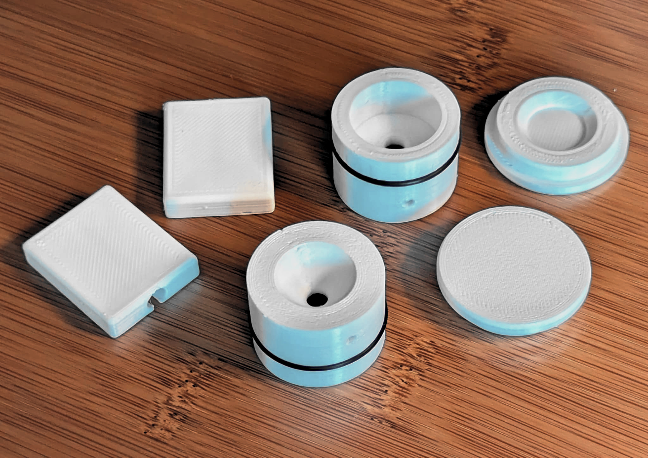
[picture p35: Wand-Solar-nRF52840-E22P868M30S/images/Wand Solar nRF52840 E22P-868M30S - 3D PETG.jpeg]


## 32mm PVC pipe

**BE CAREFUL** when choosing the 32mm PVC pipe !  
The internal diameter **must be at least 28mm**.  
Some low-quality pipes have a much smaller diameter.  

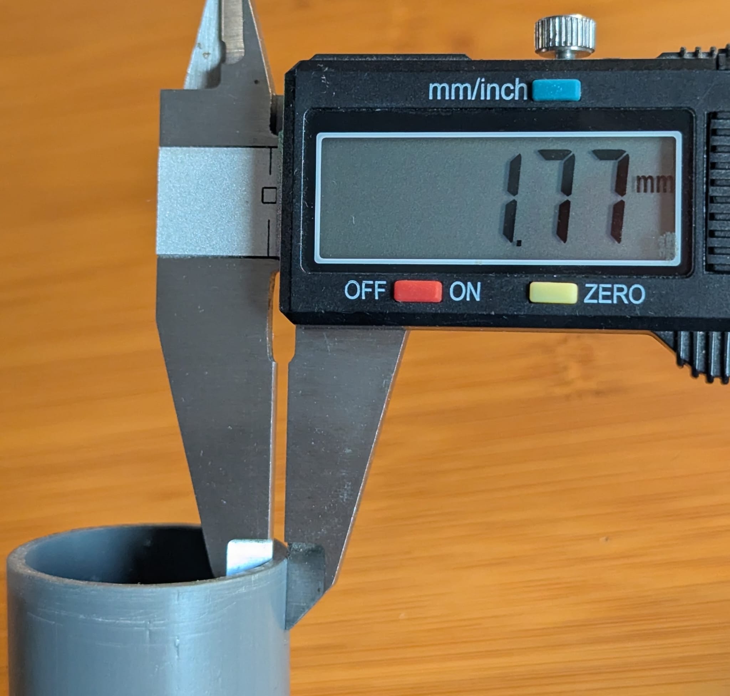
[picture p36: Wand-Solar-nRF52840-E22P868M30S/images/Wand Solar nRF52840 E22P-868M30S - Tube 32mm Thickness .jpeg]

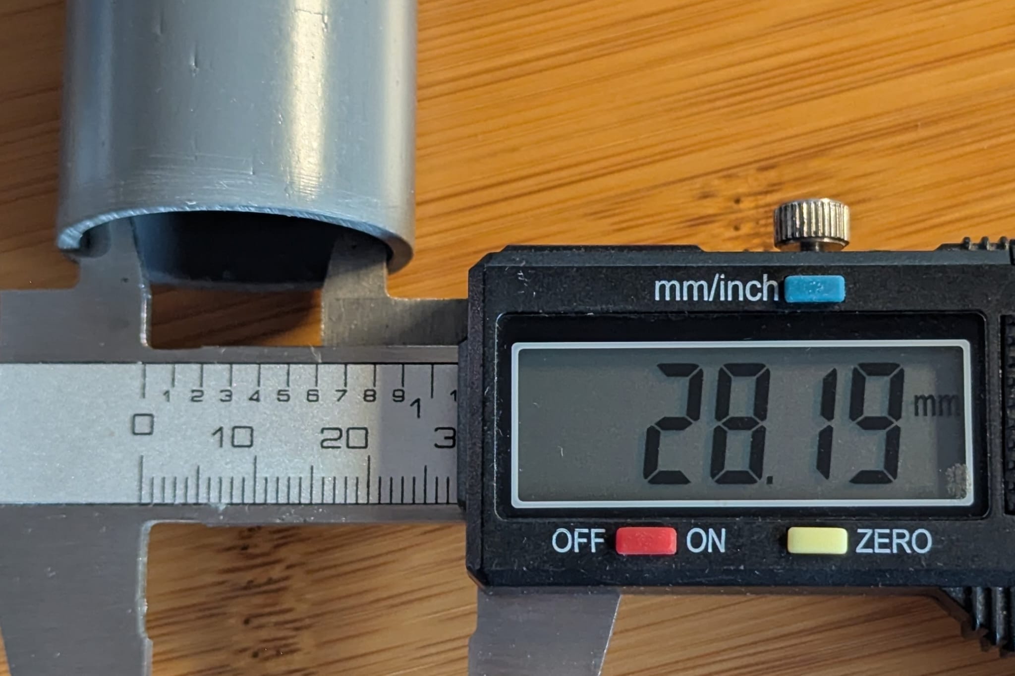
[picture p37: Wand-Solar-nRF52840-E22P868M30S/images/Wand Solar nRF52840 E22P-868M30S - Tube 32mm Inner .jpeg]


<table border="1">
  <tr><th>Top</th><th>Bottom</th></tr>
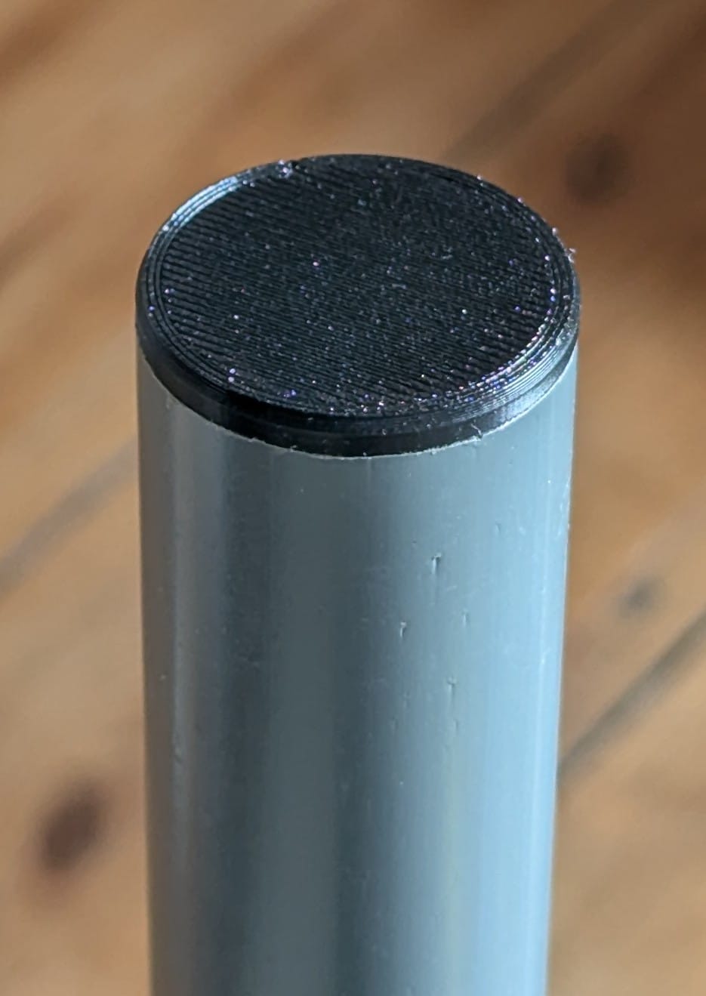
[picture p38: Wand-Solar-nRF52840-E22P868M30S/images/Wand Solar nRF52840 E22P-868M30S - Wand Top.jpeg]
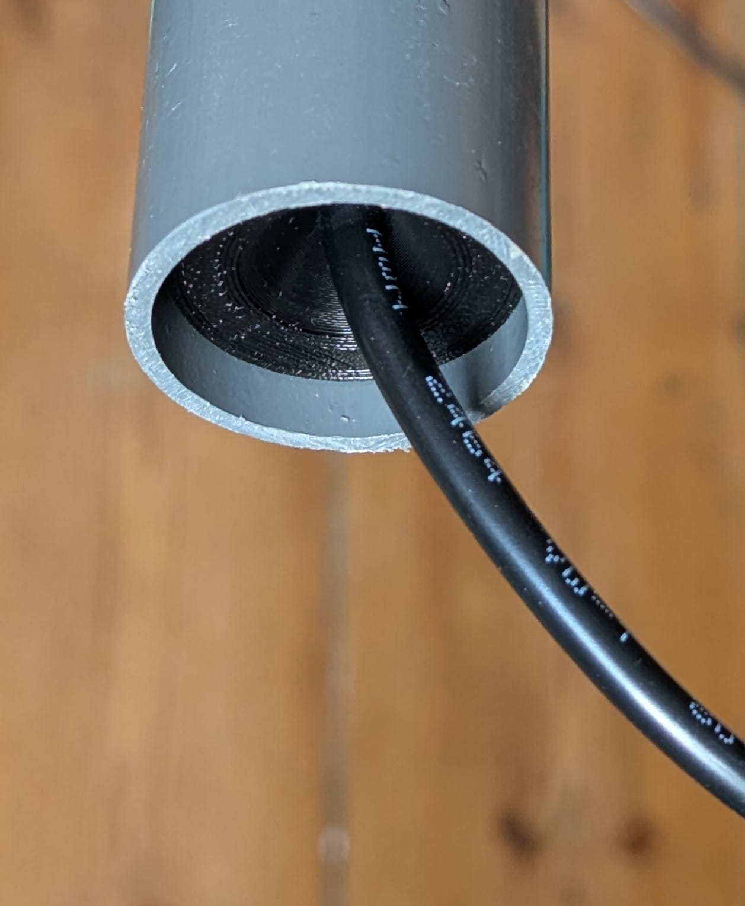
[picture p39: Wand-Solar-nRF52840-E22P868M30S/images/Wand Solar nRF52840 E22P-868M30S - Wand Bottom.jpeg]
  <tr><td></td><td></td></tr>
  <tr><td>The top is glued directly onto the tube.</td><td>The bottom contains an O-ring and is held in place by a screw on the side.</td></tr>
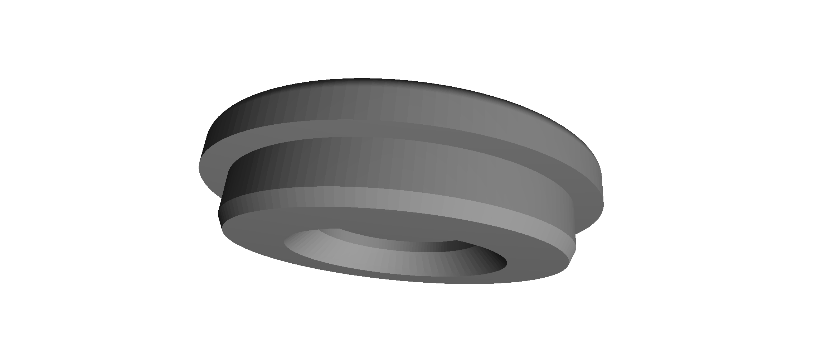
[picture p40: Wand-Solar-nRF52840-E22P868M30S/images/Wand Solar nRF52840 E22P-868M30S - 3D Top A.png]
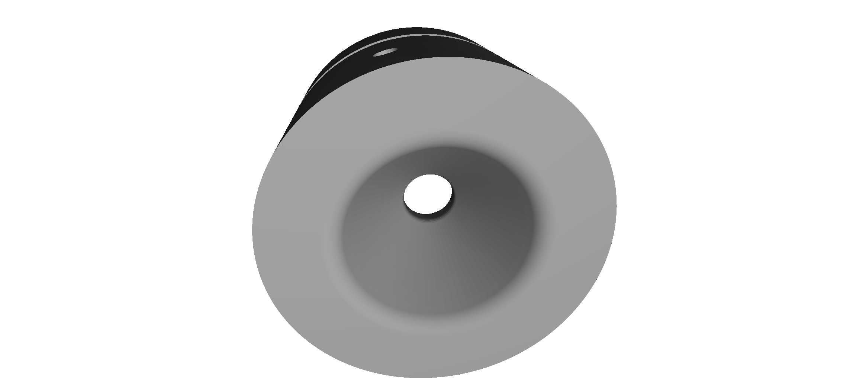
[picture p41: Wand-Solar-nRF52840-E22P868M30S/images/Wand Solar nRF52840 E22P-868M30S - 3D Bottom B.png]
  <tr><td></td><td></td></tr>
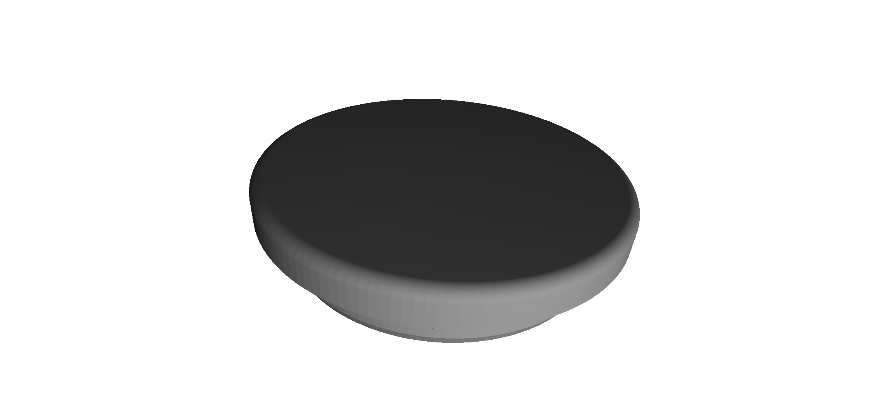
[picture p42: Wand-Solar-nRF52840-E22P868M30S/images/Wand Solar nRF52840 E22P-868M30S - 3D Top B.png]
  <tr><td></td><td></td></tr>
  <tr><td></td><td></td></tr>
</table>

Above all, **don't forget to tie a knot in the cable** !
Otherwise, it’s difficult, or even impossible, to pull on the cable to disassemble it !


**3mm** Hole :  



## Solar Panel



## Batteries Holder

<table border="1">
  <tr><td></td></tr>
  <tr><td></td></tr>
</table>

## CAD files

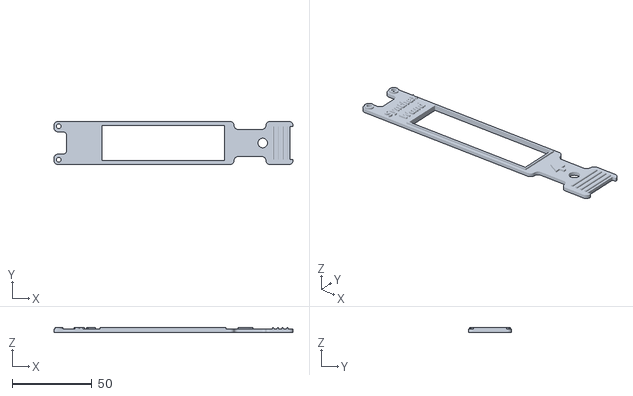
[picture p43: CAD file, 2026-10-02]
Wand-Solar-nRF52840-E22P868M30S/3D-Parts/Wand 21700 Li-ion Holder.stl
150.0 x 27.0 x 3.00

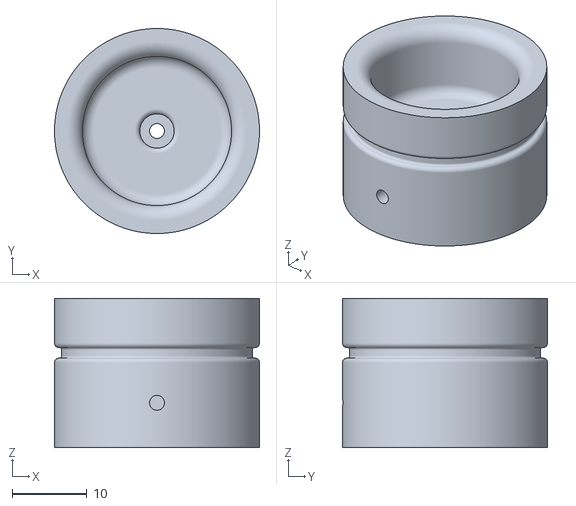
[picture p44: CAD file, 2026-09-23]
Wand-Solar-nRF52840-E22P868M30S/3D-Parts/Wand Bottom v2.stl
27.5 x 27.5 x 20.0

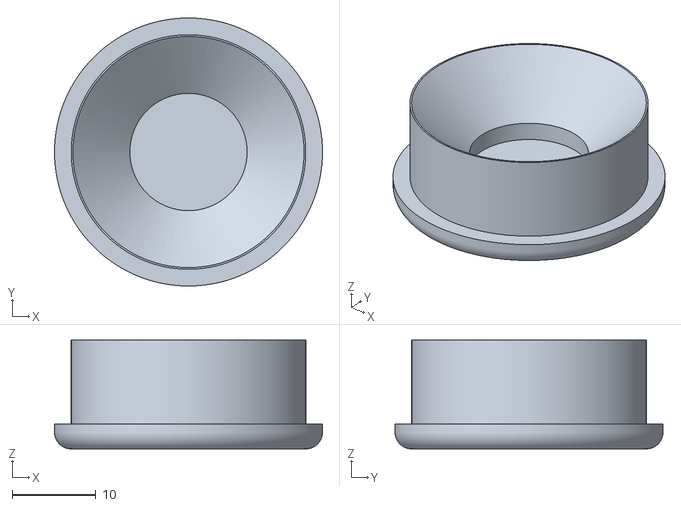
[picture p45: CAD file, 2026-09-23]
Wand-Solar-nRF52840-E22P868M30S/3D-Parts/Wand Top v2.stl
32.0 x 32.0 x 13.0

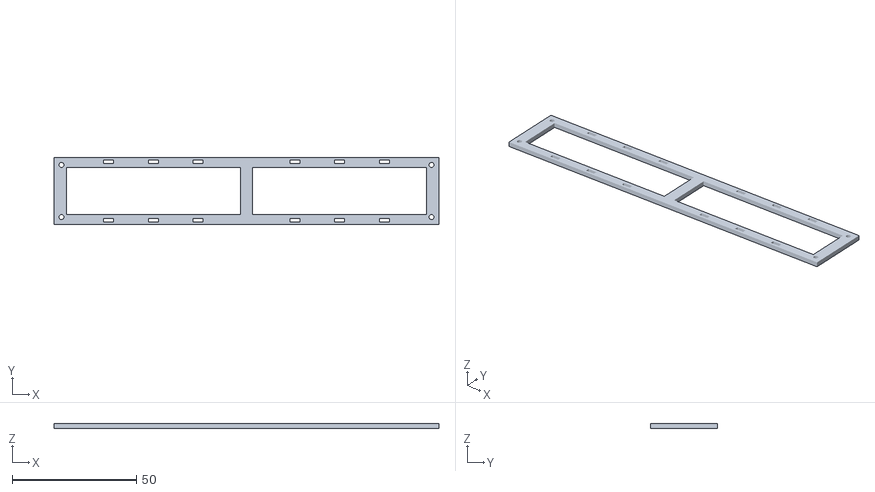
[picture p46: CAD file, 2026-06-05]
Wand-Solar-nRF52840-E22P868M30S/3D-Parts/Wand Batteries Holder.stl
155.0 x 27.0 x 2.00

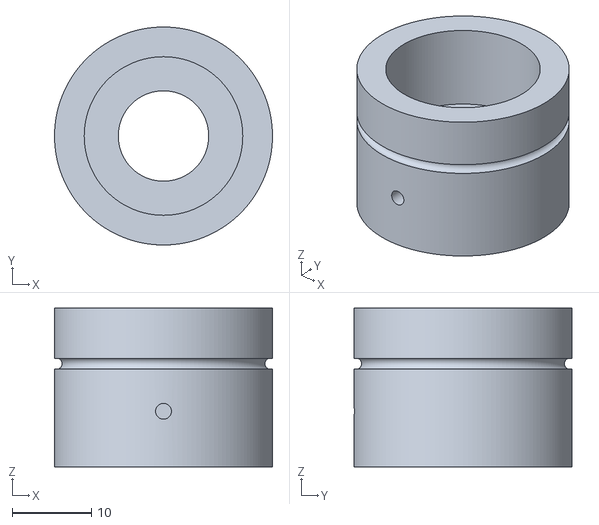
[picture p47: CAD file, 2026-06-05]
Wand-Solar-nRF52840-E22P868M30S/3D-Parts/Wand Bottom USB Light.stl
27.5 x 27.5 x 20.0

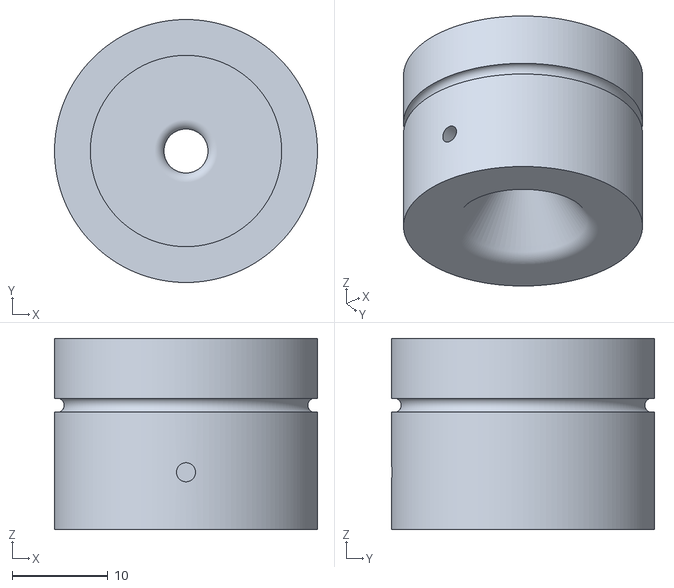
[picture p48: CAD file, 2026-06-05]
Wand-Solar-nRF52840-E22P868M30S/3D-Parts/Wand Bottom Light.stl
27.5 x 27.5 x 20.0

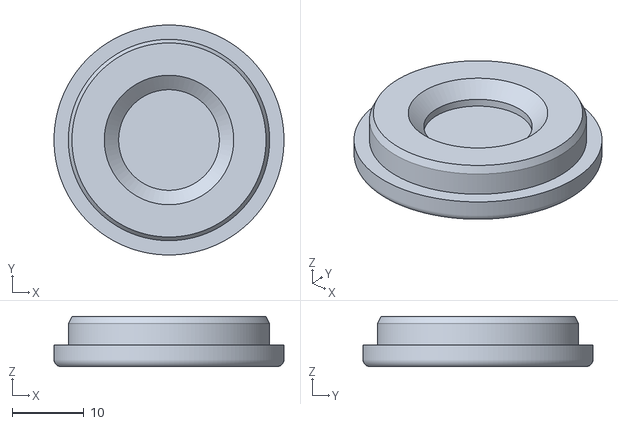
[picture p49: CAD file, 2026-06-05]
Wand-Solar-nRF52840-E22P868M30S/3D-Parts/Wand Top Light.stl
32.0 x 32.0 x 7.00

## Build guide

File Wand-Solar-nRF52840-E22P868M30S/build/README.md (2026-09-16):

## GPS Installation (ATGM336H Module)
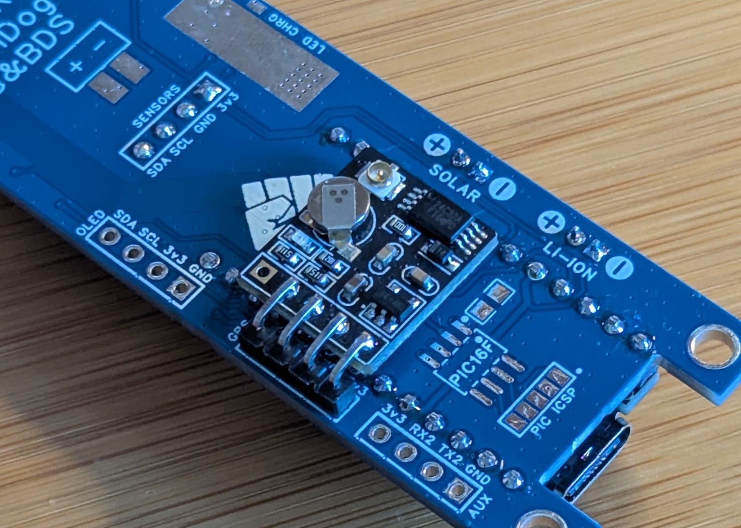
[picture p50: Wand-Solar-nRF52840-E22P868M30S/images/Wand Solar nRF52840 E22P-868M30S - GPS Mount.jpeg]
  

Pay close attention to the areas marked by the red arrows to ensure there is no contact with other solder joints !
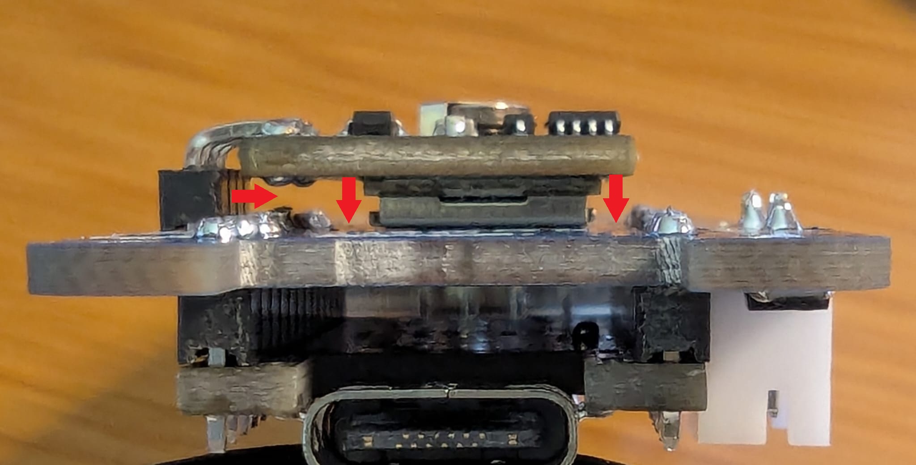
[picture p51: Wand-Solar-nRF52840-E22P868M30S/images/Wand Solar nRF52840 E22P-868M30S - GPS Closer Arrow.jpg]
  

**And Make sure the GPS antenna connector DOES NOT touch the module's battery !**
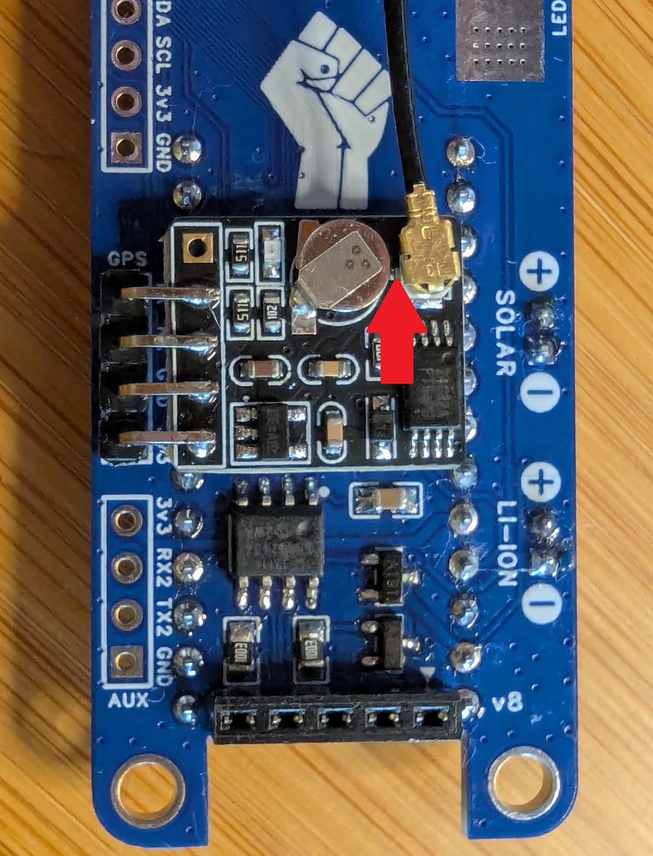
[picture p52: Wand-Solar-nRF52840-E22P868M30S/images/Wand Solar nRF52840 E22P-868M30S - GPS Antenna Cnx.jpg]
  

## Batteries Holder
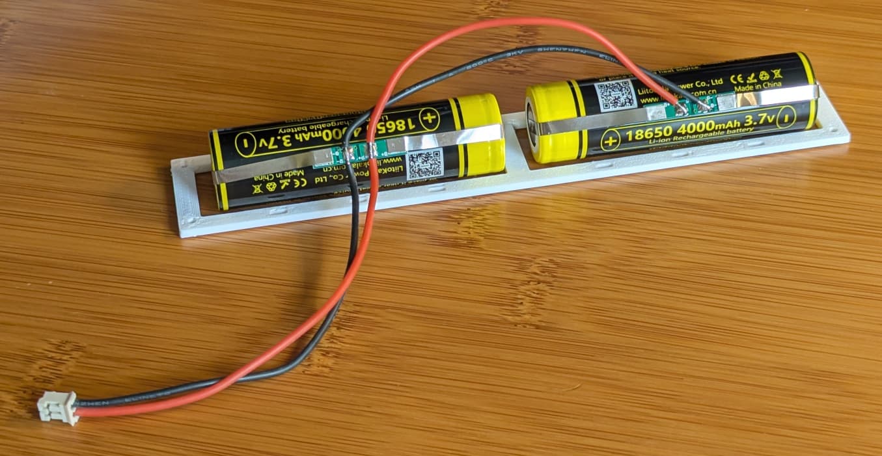
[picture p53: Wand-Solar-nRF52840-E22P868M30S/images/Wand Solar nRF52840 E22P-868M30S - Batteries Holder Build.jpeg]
  
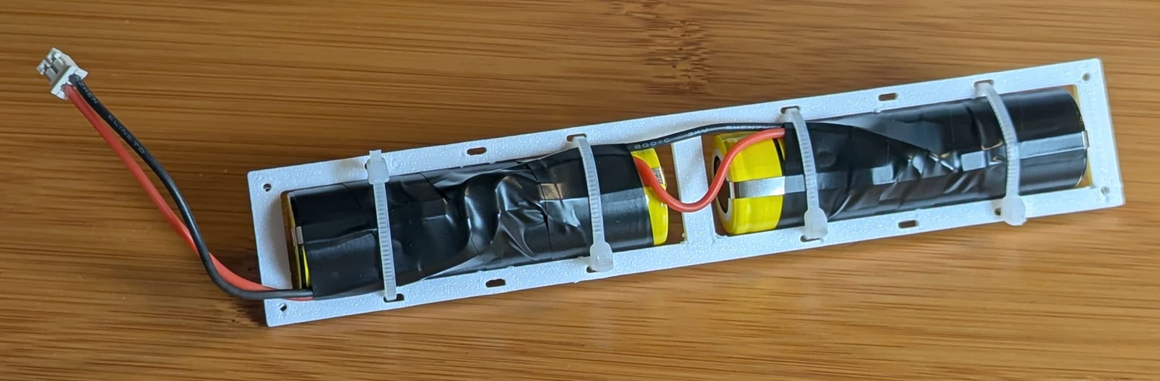
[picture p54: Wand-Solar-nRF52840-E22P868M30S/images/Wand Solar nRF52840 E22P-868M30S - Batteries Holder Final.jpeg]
  
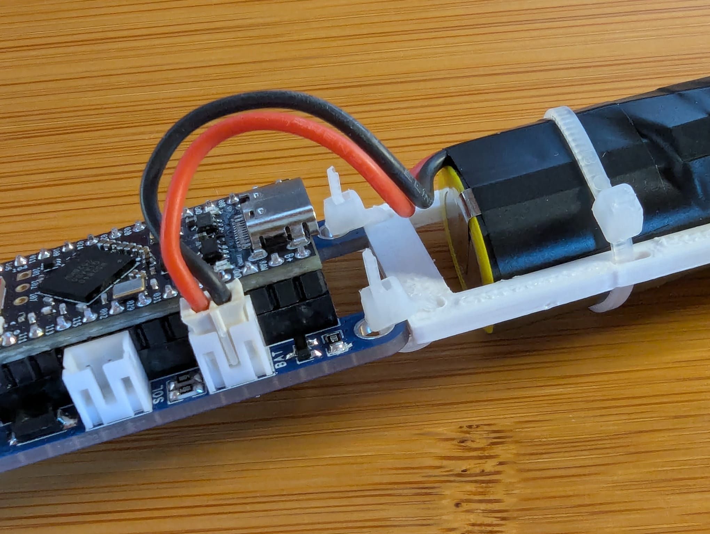
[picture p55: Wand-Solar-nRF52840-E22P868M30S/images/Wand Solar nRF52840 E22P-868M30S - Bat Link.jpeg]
  

## Under construction
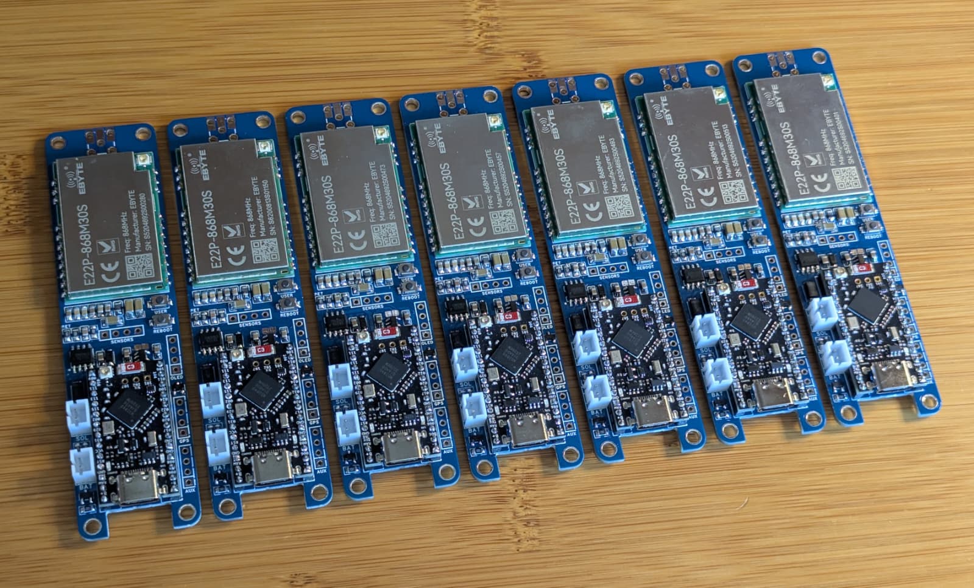
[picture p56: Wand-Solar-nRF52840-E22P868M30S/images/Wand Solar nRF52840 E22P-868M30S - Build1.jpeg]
  
  
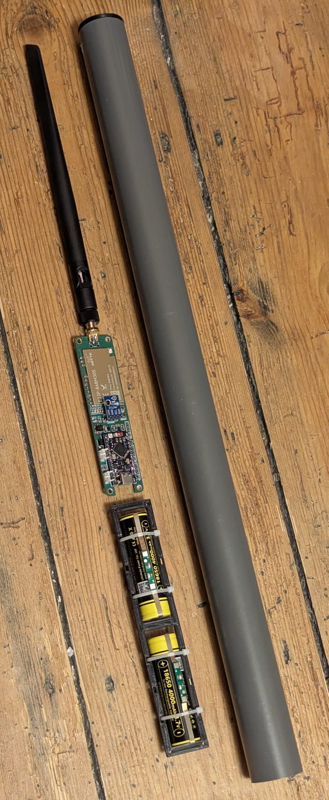
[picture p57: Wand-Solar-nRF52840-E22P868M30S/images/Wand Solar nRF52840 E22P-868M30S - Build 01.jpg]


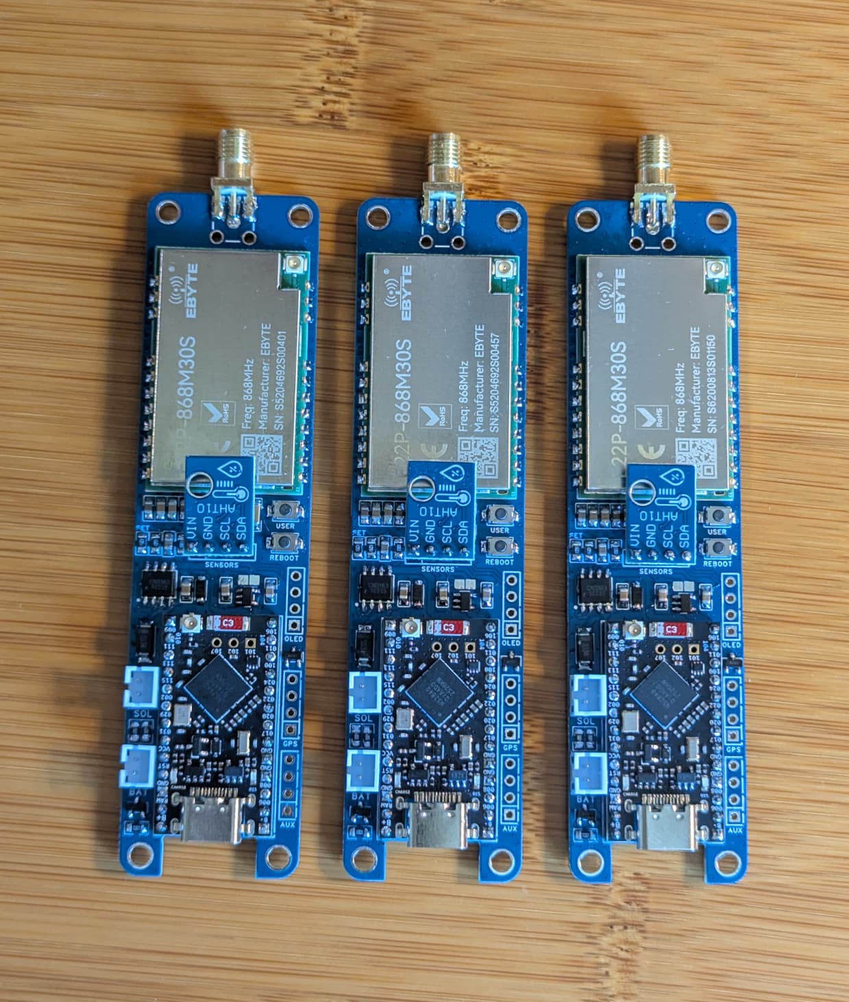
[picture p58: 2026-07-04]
Wand-Solar-nRF52840-E22P868M30S/images/Wand Solar nRF52840 E22P-868M30S - Build3.jpeg

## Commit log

2026-05-12 Create pcb
2026-05-12 Update and rename pcb to README.md
2026-06-02 Create Schematics
